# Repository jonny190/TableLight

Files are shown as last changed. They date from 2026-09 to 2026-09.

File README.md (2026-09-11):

# TableLight

A 3D-printable, battery-powered, USB-C rechargeable table lamp in the classic "Poldina" shape - honeycomb
disc base, thin stem, down-firing cone shade with a white top - running [WLED](https://kno.wled.ge/) on an
ESP32, with a capacitive touch pad hidden under the white top plate.

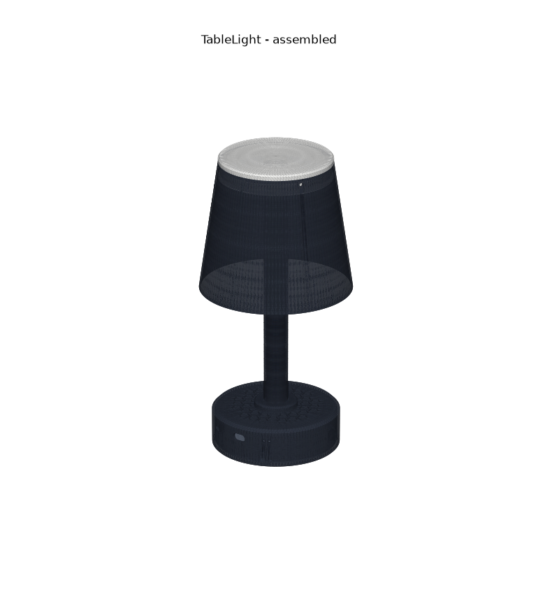
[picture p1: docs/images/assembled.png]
assembled


| | |
|---|---|
| Size | Ø118 x 36 mm base, Ø22 stem, shade Ø140 -> Ø104 x 120 mm, 279 mm tall overall |
| Light | 24-LED SK6812 RGBW (or WS2812B) ring under the head, shining down through a diffuser; optional second 16-LED ring |
| Power | 1 **or** 2 x 18650 Li-ion in parallel (1S) in the base, USB-C charging (1 A) in the base, runs while charging |
| Control | WLED app / web UI / Home Assistant + touch on the white top (ESP32 native touch) |
| Electronics | one custom Ø110 mm PCB in the base (KiCad board + PCBWay Gerber/BOM/CPL package included); flashes WLED over the same USB-C port |
| Runtime | ~5 h at full reading brightness, ~12 h at mood brightness with two 3500 mAh cells (half with one cell) |

## What is in this repository

```
cad/tablelight.py          parametric CAD (Python: trimesh + manifold) - ALL dimensions live here
cad/stl/                   ready-to-print STL files (6 parts)
hardware/pcb/              custom controller PCB: SKiDL circuit, KiCad 7 board (kicad/), PCBWay fab package
                           (fab/: Gerbers, drill, BOM, pick-and-place), board generator, design notes
firmware/wled/             WLED build override + settings for this lamp
docs/BOM.md                complete bill of materials (printed parts, electronics, hardware, consumables)
docs/PRINTING.md           print settings and orientation per part
docs/ASSEMBLY.md           step-by-step build
docs/WLED_SETUP.md         WLED configuration (pins, 2D matrix, touch button, battery, current limit)
docs/images/               renders, section drawing, PCB placement, block diagram
```

## The parts

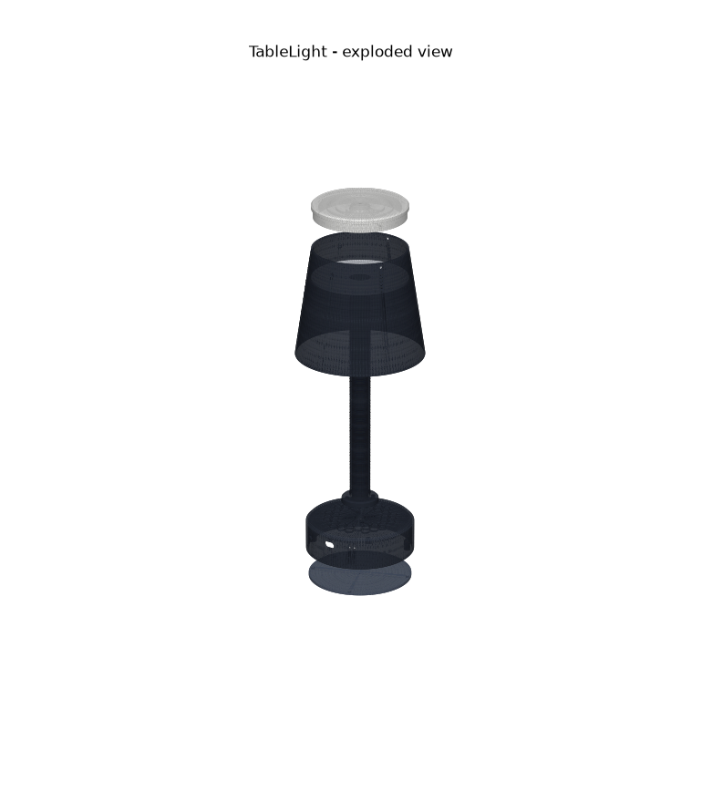
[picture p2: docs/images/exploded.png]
exploded


| STL | Qty | What it does |
|---|---|---|
| `base_shell.stl` | 1 | Honeycomb-topped base disc: the PCB hangs under its deck (components facing down), USB-C, power switch and charge LEDs in the side wall, 1-2 x 18650 inside |
| `base_bottom_plate.stl` | 1 | Screw-on floor with rubber feet; remove it to reach the batteries, buttons and connectors |
| `stem.stl` | 1 | Ø22 hollow stem with a Ø40 foot flange; screwed to the deck from below, carries the wires to the head |
| `head_plate.stl` | 1 | White top: stem socket, two LED-ring channels on the underside, skirt that the shade screws to, touch-pad recess |
| `cone_shade.stl` | 1 | Opaque cone Ø140 -> Ø104, open at the bottom; 3 nubs hold the diffuser, 3 radial screws hold it to the head |
| `head_diffuser.stl` | 1 | Ø104 translucent disc 14 mm under the LED ring so you never see bare LEDs from below |

Section through the assembled lamp (all clearances are modelled, nothing is glued):

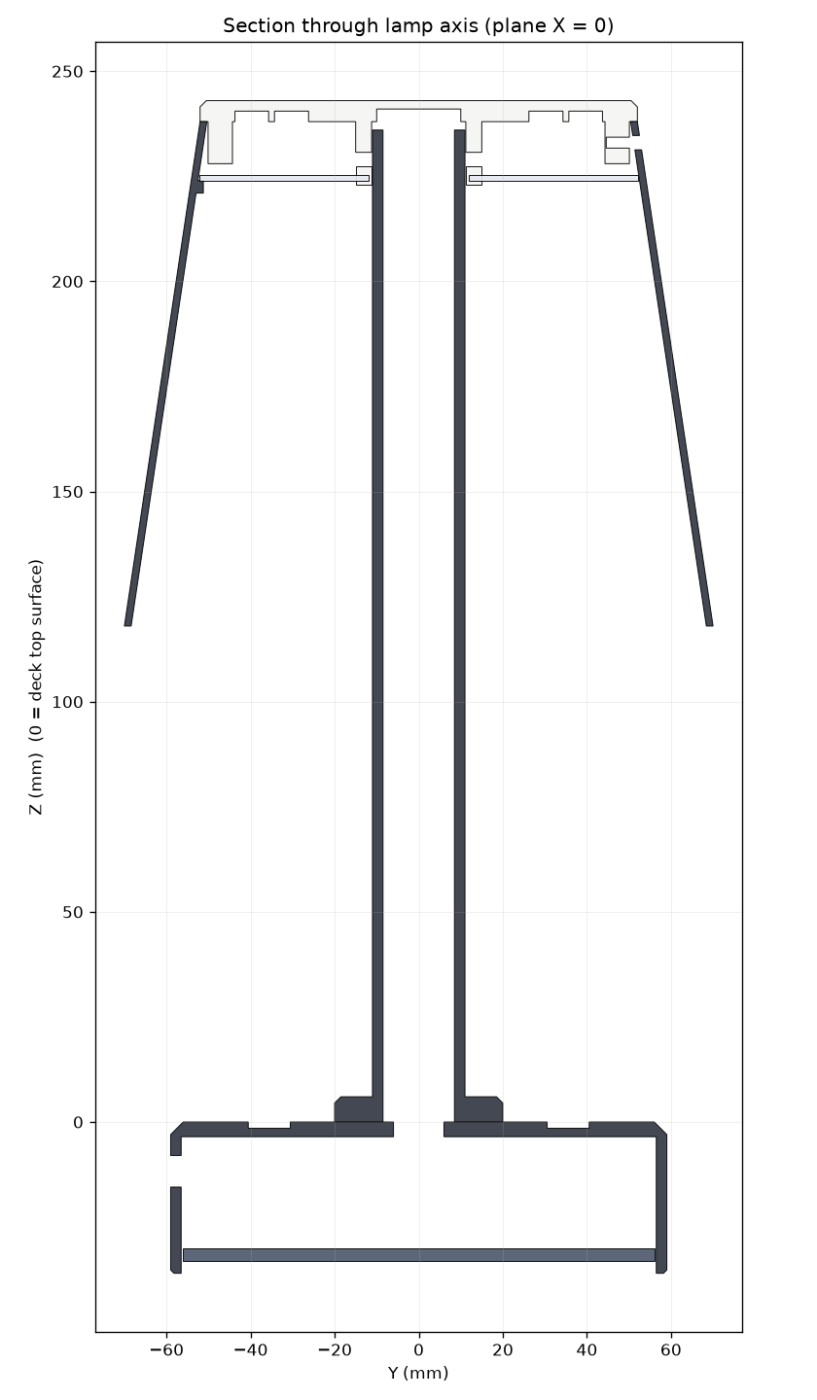
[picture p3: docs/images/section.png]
section


## Electronics in one picture

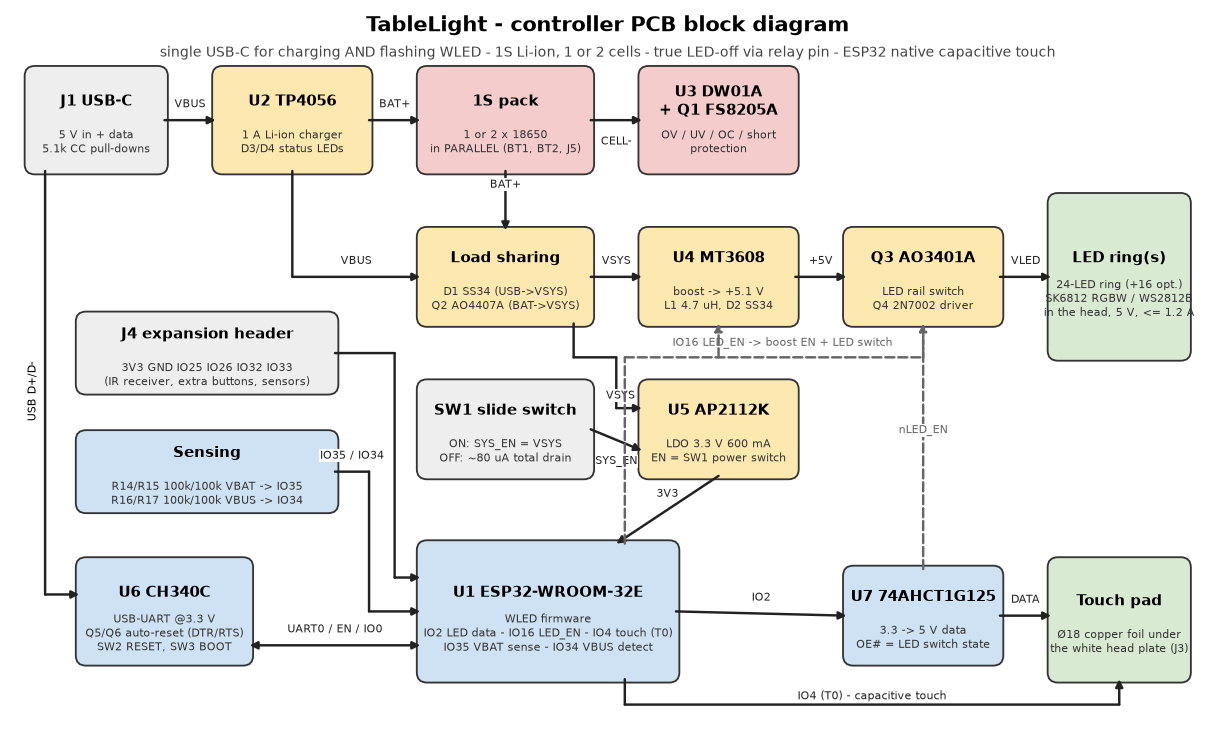
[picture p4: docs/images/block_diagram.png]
block diagram


Power path: USB-C -> TP4056 charger -> 1S pack (DW01A/FS8205A protected) -> load-share (Schottky + P-FET)
-> `VSYS` -> MT3608 boost 5.1 V -> P-FET LED switch -> LED ring in the head (via the stem); `VSYS` -> 3.3 V LDO -> ESP32-WROOM-32E.
The USB-C data lines go to a CH340C with auto-reset, so WLED is flashed through the charging port.
A slide switch in the base wall is the hard off (about 80 uA drain). WLED's "relay pin" cuts the LED rail so
standby is only the ESP32.

See `hardware/pcb/README.md` for the design rationale and `hardware/pcb/SCHEMATIC.md` for every net.

## Build order (short version)

1. Print the six parts (`docs/PRINTING.md`). Fit 12 x M3 heat-set inserts.
2. Order the PCB: upload `hardware/pcb/fab/tablelight-gerbers.zip` to PCBWay (`hardware/pcb/fab/README.md` has the form values). Flash WLED (`docs/WLED_SETUP.md`).
3. Tape the LED ring into the head plate, stick the touch foil in its recess, run the wires down the stem (`docs/ASSEMBLY.md`).
4. Screw the stem to the deck, plug the PCB in, screw the PCB to the deck bosses, fit 1 or 2 cells, screw the floor on.
5. Push the diffuser up into the cone, screw the cone to the head, push the head onto the stem and fix it with two screws. Done.

## Regenerating the CAD / PCB files

```
pip install -r requirements.txt
python3 cad/tablelight.py                    # STLs -> cad/stl, renders -> docs/images
python3 hardware/pcb/tablelight_netlist.py   # tablelight.net, bom_pcb.csv, SCHEMATIC.md
python3 hardware/pcb/board_outline.py        # outline.dxf, placement.svg, PLACEMENT.md
python3 hardware/pcb/build_board.py          # KiCad board -> autoroute -> DRC -> fab/ (needs KiCad 7 + freerouting.jar)
python3 docs/block_diagram.py                # block_diagram.svg/.png
```

Change a value in the `P = dict(...)` block at the top of `cad/tablelight.py` (shade size and taper, stem length,
base diameter, honeycomb size, ring diameters...) and everything that depends on it - head socket, cone screw
positions, wall openings, PCB placement drawing - follows. The stem is 236 mm tall as printed; set `stem_len`
lower if your printer's Z is under 240 mm.

## Safety notes

* Cells in parallel must be the same model and within ~0.1 V of each other when inserted. Never mix a fresh
  and a flat cell.
* The board has over/under-voltage, over-current and short protection (DW01A + FS8205A), but a lamp is a closed
  plastic box: keep the WLED current limit at or below 1200 mA and do not leave it charging on a cushion.
* Use a 5 V USB-C supply rated 2 A or more when charging and running at the same time.

## License

MIT for the code and design files. WLED is licensed separately by its authors.

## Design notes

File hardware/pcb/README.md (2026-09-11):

# TableLight controller PCB

Round Ø110 mm, 2 layer, 1.6 mm FR4. Lives in the base, components facing down, screwed to four bosses
under the base deck. One board does everything: charging, protection, boost, ESP32 + WLED, USB flashing,
LED power switching, touch input, battery sensing.

**Ready to order:** `fab/tablelight-gerbers.zip` (+ `fab/tablelight-bom.csv`, `fab/tablelight-cpl.csv` for
assembly). Ordering parameters and a pre-order checklist are in `fab/README.md`. The KiCad 7 board is
`kicad/tablelight.kicad_pcb`: hand-placed, autorouted (freerouting, 2 layers, 58 vias), GND pours both
sides, KiCad DRC clean (0 unconnected, 0 clearance/edge/hole/courtyard errors; remaining report entries
are silkscreen cosmetics).

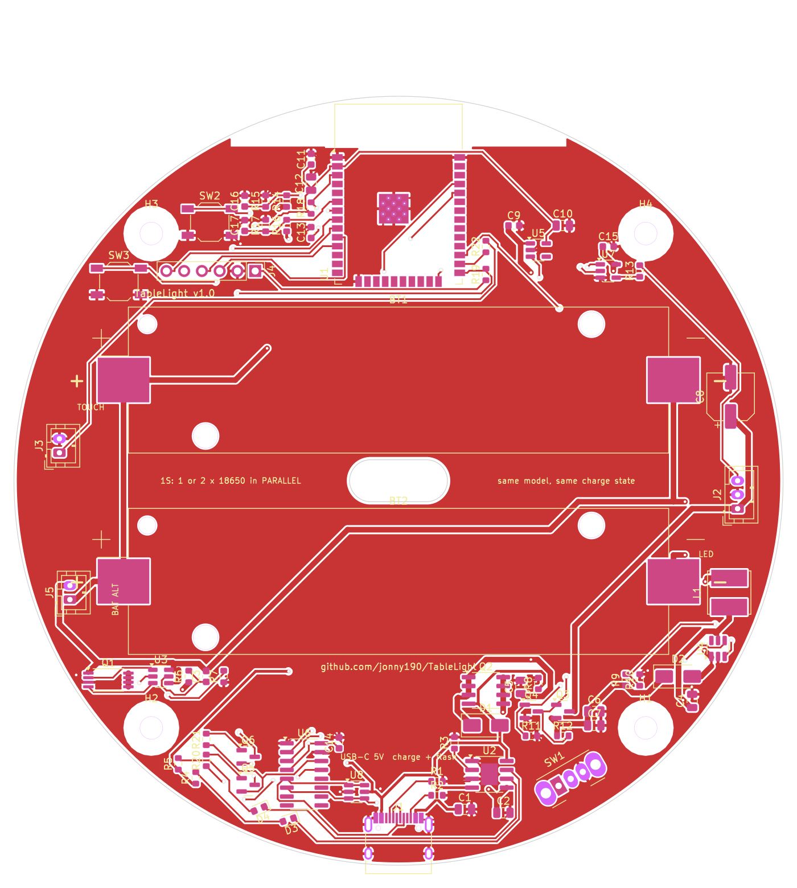
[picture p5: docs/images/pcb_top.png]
top


block diagram

| File | What |
|---|---|
| `build_board.py` | **the board** (KiCad 7 pcbnew API): places every footprint from the table inside it, autoroutes with freerouting, pours GND, runs DRC, exports `fab/` |
| `kicad/tablelight.kicad_pcb` | the finished board; `kicad/drc_report.txt` is the DRC of exactly this file |
| `fab/` | PCBWay package: Gerbers + drill zip, assembly BOM, pick-and-place, ordering notes |
| `tablelight_netlist.py` | **the circuit** (SKiDL). Run it to regenerate the three files below |
| `tablelight.net` | KiCad netlist with footprints assigned. pcbnew: *File > Import Netlist* |
| `SCHEMATIC.md` | every net with every pin, plus per-component pin tables |
| `bom_pcb.csv` | PCB bill of materials (refs, values, example MPNs, footprints) |
| `board_outline.py` | reads the enclosure parameters and writes the three files below |
| `outline.dxf` | Edge.Cuts (Ø110 circle + centre wire slot) and reference layers. pcbnew: *File > Import > Graphics* |
| `placement.svg` / `PLACEMENT.md` | where the connectors, holders, module and keep-outs must go |

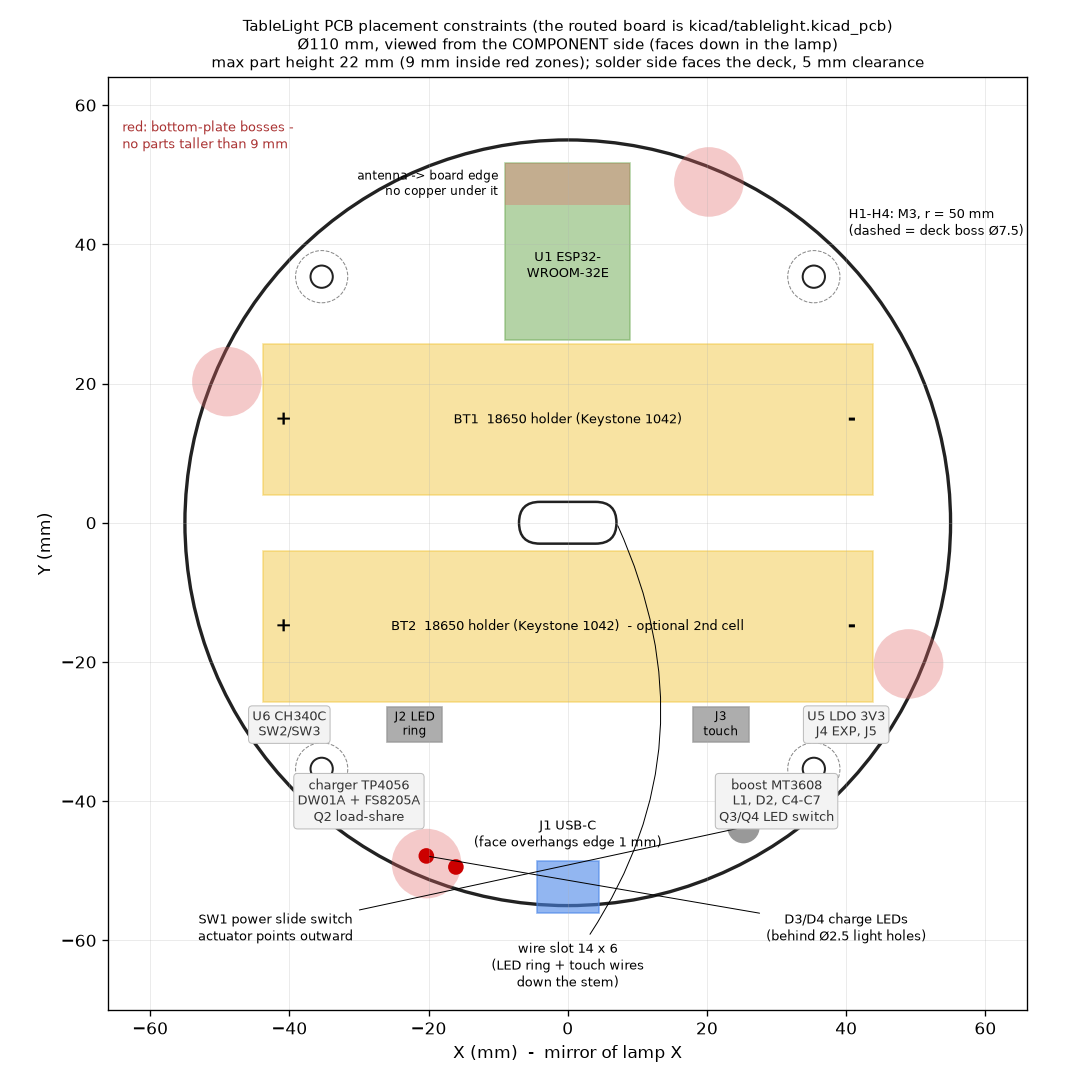
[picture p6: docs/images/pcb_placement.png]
placement


## Regenerating the board

```
sudo apt install kicad            # KiCad 7 (pcbnew Python module + kicad-cli)
curl -L -o hardware/pcb/tools/freerouting.jar \
     https://github.com/freerouting/freerouting/releases/download/v1.9.0/freerouting-1.9.0.jar
python3 hardware/pcb/build_board.py               # place -> route -> zones -> DRC -> fab/
```

`build_board.py` reads the circuit from `tablelight_netlist.py` and the mechanical constraints from
`cad/tablelight.py`; component positions are the `PLACEMENT` table at the top of the script (KiCad
coordinates, Y down, component side view). Change a position there and rerun: the router, pours, DRC and
Gerbers are regenerated. Design rules baked in: 0.25 mm signal / 0.8 mm power tracks, 0.2 mm clearance,
0.7/0.35 mm vias, 0.4 mm copper-to-edge, GND pour both layers with thermal reliefs.

Keep-outs that the script enforces: no copper under the module antenna (both layers), no copper on the
component side within 4 mm of the four mounting holes (screw heads), courtyards clear of the two
Keystone 1042 holders (87.6 x 21.7 mm each).

If you would rather lay it out by hand: import `tablelight.net` into an empty pcbnew, import `outline.dxf`
onto Edge.Cuts, and follow `PLACEMENT.md`. Power nets (`BAT+`, `CELL-`, `GND`, `VSYS`, `+5V`, `VLED`) carry
up to 2.5 A: 0.8 mm+ traces or pours. Height limits from the enclosure: 22 mm anywhere on the component
side, 9 mm inside the four boss zones, 3 mm of lead length on the solder side.

## Design notes and calculations

**Cells.** 1S, one or two 18650 in parallel. Parallel cells need no balancing; they must be the same model
and within ~0.1 V when inserted. `J5` is a JST-PH alternative for a wire-lead holder or a pouch cell.

**Protection.** DW01A + FS8205A, the same topology as the ubiquitous TP4056 module: the two FETs sit in the
cell-negative path, `CELL-` is the raw cell terminal and `GND` is the protected side. Over-discharge 2.4 V,
over-charge 4.3 V, over-current ~3 A (with the 8205A's 2 x 25 mOhm). Dissipation at 2.5 A: 0.3 W.

**Charger.** TP4056, `R3` = 1.2k -> 1.0 A. 2 x 3500 mAh charge in about 8 h, one cell in 4 h. Use `R3` = 2k
(0.58 A) if it will mostly be charged from a laptop port. Dissipation worst case (5 V - 3.0 V) x 1 A = 2 W at
the start of charge: give U2's pad a big pour, the IC throttles thermally anyway. `TEMP` is grounded (no NTC).
CC1/CC2 pull-downs (5.1k) so USB-C to USB-C cables and PD chargers supply 5 V.

**Load sharing.** `D1` (SS34) feeds `VSYS` from `VBUS` while plugged in; `Q2` (AO4407A, 12 mOhm) connects the
pack to `VSYS` only when `VBUS` is absent (gate tied to `VBUS`, `R8` pull-down). The charger therefore only
ever sees the cell, so termination works, and the lamp runs at full power while charging. Q2 drop at 2.5 A:
30 mV.

**Boost.** MT3608 at 1.2 MHz, `R9`/`R10` = 75k/10k -> 5.1 V. 4.7 uH / 4 A inductor, 2 x 22 uF in, 2 x 22 uF
out plus 100 uF on `VLED`. Practical continuous output from a 3.3 V cell is about 1.5 A at 5 V, hence the
WLED current limit of 1.2 A (24 + 16 LEDs at full white would ask for 2.4 A). `EN` is driven by `LED_EN`
(GPIO16), so the converter idles when the light is off.

**LED rail switch.** `Q3` (AO3401A) between `+5V` and `VLED`, driven by `Q4` (2N7002) from `LED_EN`. WLED's
"relay pin" feature raises GPIO16 whenever the strip is on. `R11` keeps the LEDs off during boot. With the
rail off the ring draws nothing, so standby is only the ESP32 (~80 mA with WiFi, ~10 mA with WiFi sleep).

**Level shifter.** SN74AHCT1G125 powered from `+5V`, input from GPIO2, 330 R into the data line. Its `OE#`
is tied to the Q3 gate node, so the data output is high-impedance while the rail is off - no back-powering
the ring through its data pin.

**3.3 V.** AP2112K-3.3 from `VSYS` (works from 3.0 to 5 V input, 250 mV dropout at 600 mA). Its `EN` pin is
the power switch `SW1`: OFF disables the LDO, the ESP32 dies, `LED_EN` falls, boost and LED rail switch off.
Off-state drain is about 80 uA (LDO + DW01 + the two 100k/100k dividers + the boost FB divider): years.

**USB-UART.** CH340C at 3.3 V (`V3` tied to `VCC`), no crystal. Standard NodeMCU auto-reset with two NPNs
(DTR/RTS -> EN/IO0) so esptool and the WLED web installer work hands-free. `SW2` RESET and `SW3` BOOT for
manual recovery. USBLC6-2SC6 on D+/D- is optional ESD protection.

**ESP32 pins.** GPIO2 LED data, GPIO16 LED rail enable (relay pin), GPIO4 (T0) touch, GPIO35 battery voltage
(100k/100k, x2.0), GPIO34 VBUS detect (100k/100k), GPIO25/26/32/33 on the expansion header `J4`. Strapping
pins 12 and 15 are left unconnected; GPIO0 has a 10k pull-up.

**Touch.** ESP32 native capacitive sensing through 2 mm of PLA with a Ø18 foil disc under the head plate.
`R22` (1k) is ESD/series protection; use 0 R if the sensitivity is marginal. The touch wire runs 250 mm down
the stem next to the LED wires: keep it away from the data wire if possible (twist it with the GND wire).

## Bring-up (bench, before installing)

1. No cells. Plug USB-C: D3 or D4 flashes, `VSYS` ~4.6 V, `3V3` = 3.3 V with `SW1` on, the CH340 enumerates.
2. Flash WLED. It should boot and start its AP.
3. Insert one cell. Unplug USB: the lamp keeps running from the cell (Q2). `BAT+` divider reads on GPIO35.
4. Connect the ring to `J2`, turn the light on in WLED: `VLED` = 5.1 V only while on.
5. Plug USB with the cell in: D3 (red) while charging, D4 (green) when done. Q2 should be cold.

## Ordering

See `fab/README.md` for the PCBWay form values. Any 2-layer service works (JLCPCB, Aisler, OSH Park take
the same zip). All SMD parts are on one side; the THT parts (JST headers, pin header, slide switch) and the
SMD-mount 18650 holders are a 20 minute hand solder if you do not order assembly.

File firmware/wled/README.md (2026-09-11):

# WLED firmware notes

* `platformio_override.ini` - drop into a WLED checkout to build the `tablelight` environment with this
  board's pin defaults and the Battery usermod. Verified against the WLED 0.15 build-flag names
  (`DATA_PINS`, `RLYPIN`, `BTNPIN`, `BTNTYPE`, `USERMOD_BATTERY_*`); if a future WLED renames one, the compiler
  will tell you and the equivalent setting can always be made in the web UI (`docs/WLED_SETUP.md`).
* No custom code is required. Everything the lamp does (touch toggle, LED rail switching, 2D effects,
  battery readout) is stock WLED functionality configured for these pins. The LED count default is 24 (one ring); set 40 in the UI if you fit the second ring.

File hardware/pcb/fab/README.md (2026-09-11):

# TableLight PCB - PCBWay fabrication package

Everything in this folder is generated by `../build_board.py` from the KiCad board
`../kicad/tablelight.kicad_pcb`. Upload `tablelight-gerbers.zip` to PCBWay; if you also want them to
assemble the SMD side, add `tablelight-bom.csv` and `tablelight-cpl.csv`.

| File | Use |
|---|---|
| `tablelight-gerbers.zip` | Gerber RS-274X (copper, mask, paste, silk, outline) + Excellon drill + drill map PDF |
| `tablelight-bom.csv` | PCBWay assembly BOM (Designator, Qty, MPN, Description, Package, SMD/THT) |
| `tablelight-cpl.csv` | pick-and-place (Designator, Mid X, Mid Y, Layer, Rotation), top side, mm |
| `../kicad/tablelight.kicad_pcb` | the board itself (KiCad 7) for any edits |
| `../kicad/drc_report.txt` | DRC report of the exact board that was exported |

## PCBWay order form - "PCB Instant Quote"

| Field | Value |
|---|---|
| Board type | Single pieces |
| Size | 110 x 110 mm (round board, Ø110, drawn in the Edge.Cuts layer; there is a 14 x 6 mm internal slot) |
| Quantity | 5 (minimum) |
| Layers | 2 |
| Material | FR-4, TG 150 |
| Thickness | 1.6 mm |
| Min track / spacing | 6/6 mil (the board uses 0.25 mm / 0.2 mm - 8 mil - so 6/6 is plenty) |
| Min hole size | 0.3 mm (smallest drill on the board is 0.3 mm; the module's thermal vias are 0.35 mm) |
| Solder mask | black (the base is black) or any colour |
| Silkscreen | white |
| Surface finish | HASL lead-free (ENIG if you order assembly) |
| Via process | tenting vias |
| Finished copper | 1 oz |
| Remove product number | yes (or let PCBWay put it under a battery holder) |

## Assembly (optional, "PCB Assembly" quote)

* Assembly side: **top only** (single-sided SMD). The board has no components on the bottom.
* Supply parts: **turnkey** with the BOM. Fill in the *Manufacturer* column or let PCBWay source
  equivalents; the *Mfg Part #* column gives a known-good part for each line.
* THT parts (BT1, BT2, J2-J5, SW1) can be left off the assembly order and hand soldered in 20 minutes.
  The USB-C receptacle (J1) is SMD with through-hole shield legs: PCBWay handles it as SMD.
* The 18650 holders (Keystone 1042) are SMD-mount and heavy; if you include them in the assembly,
  ask for them to be soldered last.
* Pad 1 of each holder is wired as the **positive** terminal (silk "+" marks at the −X end of the board).
  Confirm that orientation against the holder body before installing cells.

## What was checked before export

* KiCad DRC on the exported board (report in `../kicad/drc_report.txt`): **0 unconnected pads, 0
  clearance / edge / hole / courtyard / keep-out errors**. The report still lists ~45 silkscreen items
  (reference text touching a neighbour's pad or another label - the Gerbers are exported with silk
  subtracted from the solder-mask openings, and PCBWay clips silk on pads anyway) and 72 "footprint
  not in library table" notices, which only mean the board was generated without a project library table.
* Net list against `../tablelight_netlist.py` (same object graph feeds both the netlist and the board).
* Antenna keep-out: no copper on either layer under the ESP32 module antenna, module edge at the board edge.
* Screw-head keep-outs: no copper on the component side within 4 mm of the four M3 mounting holes.
* Mechanical positions of J1 (USB-C), SW1 and D3/D4 match the openings in `cad/tablelight.py`.

## What you should still look at before paying

This board was placed by hand (the table in `../build_board.py`) and routed by an autorouter
(freerouting), then checked by DRC. That makes it manufacturable, not necessarily pretty. Ten minutes
in KiCad are well spent on:

1. Open `../kicad/tablelight.kicad_pcb`, press `B` to refill zones, run DRC once more.
2. Look at the charger area (U2, D1, Q2): make sure the GND pour connects to the TP4056 exposed pad
   with several vias (thermal relief spokes are set to 0.4 mm).
3. The boost inductor loop (L1 - U4 pin 1 - D2): keep the autorouted tracks short; if freerouting
   detoured, drag them.
4. Confirm the USB-C receptacle's silkscreen edge line sits just outside the board edge (face 1 mm past
   the edge is intentional so the plug reaches through the 2.5 mm wall).

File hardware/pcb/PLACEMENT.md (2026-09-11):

# TableLight PCB - placement constraints (KiCad coordinates)

Origin = board centre. KiCad Y axis points DOWN, so KiCad (x, y) = (x_view, -y_view). Viewed from the component side.

Generated from `cad/tablelight.py` parameters by `board_outline.py`.

| Item | KiCad (x, y) mm | Size / notes |
|---|---|---|
| Board outline | (0, 0) | circle Ø110 mm (`outline.dxf`, layer Edge.Cuts) |
| Wire slot | (0, 0) | 14 x 6 mm rounded slot in the board centre (under the Ø12 deck hole / stem bore); keep 1 mm copper clearance |
| H1 mounting hole | (+35.36, -35.36) | Ø3.2 mm; deck boss Ø7.5 mm lands on the SOLDER side around it |
| H2 mounting hole | (-35.36, -35.36) | Ø3.2 mm; deck boss Ø7.5 mm lands on the SOLDER side around it |
| H3 mounting hole | (-35.36, +35.36) | Ø3.2 mm; deck boss Ø7.5 mm lands on the SOLDER side around it |
| H4 mounting hole | (+35.36, +35.36) | Ø3.2 mm; deck boss Ø7.5 mm lands on the SOLDER side around it |
| J1 USB-C body | (+0.00, +52.33) | receptacle mating face at y_view = -56.0 (1 mm past the edge), pointing -Y |
| SW1 slide switch | (+25.25, +43.73) | actuator radially outward at 300 deg (view); base slot 9.0x4.0 mm |
| D3 CHRG LED | (-16.07, +49.45) | at board edge, light hole Ø2.5 in the base wall |
| D4 STDBY LED | (-20.32, +47.87) | at board edge, light hole Ø2.5 in the base wall |
| U1 ESP32 module | (+0.00, -38.95) | 18.0x25.5 mm, antenna toward +Y_view (board edge); antenna zone 6.0 mm: no copper |
| Stem flange screw heads (solder side) | r = 14.5 mm at 45/135/225/315 deg | M3 heads sit in the 5 mm gap above the board: keep the solder side flat there (no tall THT leads) |
| BT1 18650 holder | (+0.00, -14.85) | 87.6x21.7 mm, long axis along X, '+' (pad 1) toward -X_view |
| BT2 18650 holder | (+0.00, +14.85) | 87.6x21.7 mm, long axis along X, '+' (pad 1) toward -X_view |
| J2 LED ring | (-22.00, +29.00) | JST-PH; wires run along the holder edge to the centre slot |
| J3 touch | (+22.00, +29.00) | JST-PH; wires run along the holder edge to the centre slot |
| Boss keep-out 1 | (-48.97, -20.28) | Ø10 mm zone: parts taller than 9 mm not allowed here |
| Boss keep-out 2 | (+20.28, -48.97) | Ø10 mm zone: parts taller than 9 mm not allowed here |
| Boss keep-out 3 | (+48.97, +20.28) | Ø10 mm zone: parts taller than 9 mm not allowed here |
| Boss keep-out 4 | (-20.28, +48.97) | Ø10 mm zone: parts taller than 9 mm not allowed here |

* Max component height anywhere on the component side: **22 mm** (bottom plate is 22.9 mm below the component face).
* Solder side: 5 mm clearance to the deck. Keep THT pins trimmed below 3 mm.
* Antenna zone: keep the +Y edge of the module flush with, or overhanging, the board edge and copper-free on all layers.
* Thermals: pour a large copper area (both sides, stitched) under the TP4056 EP and around D1/Q2; the enclosure is closed PLA.
* Battery holders carry up to ~2.5 A: use >= 1.5 mm traces or pours for BAT+, CELL-, GND, VSYS, +5V, VLED.

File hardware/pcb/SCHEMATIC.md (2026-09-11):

# TableLight controller PCB - schematic (net list form)

Generated by `tablelight_netlist.py`. The block diagram is in `../../docs/images/block_diagram.svg`; the design rationale is in `README.md` next to this file. Import `tablelight.net` into KiCad pcbnew (File > Import Netlist) to get all footprints with ratsnest, then lay the board out on `outline.dxf`.

## Nets

| Net | Pins | Connected pins |
|---|---|---|
| `GND` | 51 | C1.2, C2.2, C4.2, C5.2, C6.2, C7.2, C8.2 (-), C9.2, C10.2, C11.2, C12.2, C13.2, C14.2, C15.2, C16.2, C17.2, J1.A1 (GND), J1.A12 (GND), J1.B1 (GND), J1.B12 (GND), J1.S1 (SHIELD), J2.2, J3.2, J4.2, Q1.3 (S2), Q4.2 (S), R1.2, R2.2, R3.2, R7.1, R8.2, R10.2, R11.2, R15.2, R17.2, SW1.3, SW2.2, SW3.2, U1.1 (GND), U1.15 (GND), U1.38 (GND), U1.39 (GND), U2.1 (TEMP), U2.3 (GND), U2.9 (EP), U4.2 (GND), U5.2 (GND), U6.1 (GND), U6.15 (R232), U7.3 (GND), U8.2 (GND) |
| `VBUS` | 14 | C1.1, D1.2 (A), J1.A4 (VBUS), J1.A9 (VBUS), J1.B4 (VBUS), J1.B9 (VBUS), Q2.4 (G), R4.1, R5.1, R8.1, R16.1, U2.4 (VCC), U2.8 (CE), U8.5 (VBUS) |
| `3V3` | 11 | C10.1, C11.1, C12.1, C14.1, J4.1, R18.1, R19.1, U1.2 (3V3), U5.5 (VOUT), U6.16 (VCC), U6.4 (V3) |
| `BAT+` | 11 | BT1.1 (+), BT2.1 (+), C2.1, J5.1, Q2.5 (D), Q2.6 (D), Q2.7 (D), Q2.8 (D), R6.1, R14.1, U2.5 (BAT) |
| `VSYS` | 11 | C4.1, C5.1, C9.1, D1.1 (K), L1.1, Q2.1 (S), Q2.2 (S), Q2.3 (S), SW1.1, U4.5 (IN), U5.1 (VIN) |
| `+5V` | 8 | C6.1, C7.1, C15.1, D2.1 (K), Q3.2 (S), R9.1, R12.1, U7.5 (VCC) |
| `CELL-` | 7 | BT1.2 (-), BT2.2 (-), C3.2, J5.2, Q1.1 (S1), U3.4 (TD), U3.6 (GND) |
| `EN` | 5 | C13.1, Q5.3 (C), R18.2, SW2.1, U1.3 (EN) |
| `USB_D+` | 5 | J1.A6 (D+), J1.B6 (D+), U6.5 (UD+), U8.1 (IO1), U8.6 (IO1) |
| `USB_D-` | 5 | J1.A7 (D-), J1.B7 (D-), U6.6 (UD-), U8.3 (IO2), U8.4 (IO2) |
| `IO0` | 4 | Q6.3 (C), R19.2, SW3.1, U1.25 (IO0) |
| `LED_EN` | 4 | Q4.1 (G), R11.1, U1.27 (IO16), U4.4 (EN) |
| `PROT_FET_D` | 4 | Q1.5 (D2), Q1.6 (D2), Q1.7 (D1), Q1.8 (D1) |
| `VBAT_SENSE` | 4 | C16.1, R14.2, R15.1, U1.7 (IO35) |
| `VBUS_DET` | 4 | C17.1, R16.2, R17.1, U1.6 (IO34) |
| `nLED_EN` | 4 | Q3.1 (G), Q4.3 (D), R12.2, U7.1 (OE#) |
| `BOOST_FB` | 3 | R9.2, R10.1, U4.3 (FB) |
| `BOOST_SW` | 3 | D2.2 (A), L1.2, U4.1 (SW) |
| `DTR` | 3 | Q6.2 (E), R20.1, U6.13 (DTR#) |
| `DW01_VCC` | 3 | C3.1, R6.2, U3.5 (VCC) |
| `RTS` | 3 | Q5.2 (E), R21.1, U6.14 (RTS#) |
| `VLED` | 3 | C8.1 (+), J2.1, Q3.3 (D) |
| `CC1` | 2 | J1.A5 (CC1), R1.1 |
| `CC2` | 2 | J1.B5 (CC2), R2.1 |
| `CHRG` | 2 | D3.1 (K), U2.7 (CHRG) |
| `DTR_B` | 2 | Q5.1 (B), R20.2 |
| `DW01_CS` | 2 | R7.2, U3.2 (CS) |
| `DW01_OC` | 2 | Q1.4 (G2), U3.3 (OC) |
| `DW01_OD` | 2 | Q1.2 (G1), U3.1 (OD) |
| `IO25` | 2 | J4.3, U1.10 (IO25) |
| `IO26` | 2 | J4.4, U1.11 (IO26) |
| `IO32` | 2 | J4.5, U1.8 (IO32) |
| `IO33` | 2 | J4.6, U1.9 (IO33) |
| `LED_DATA` | 2 | U1.24 (IO2), U7.2 (A) |
| `LED_DATA_5V` | 2 | R13.1, U7.4 (Y) |
| `LED_DOUT` | 2 | J2.3, R13.2 |
| `N$1` | 2 | R3.1, U2.2 (PROG) |
| `N$2` | 2 | D3.2 (A), R4.2 |
| `N$3` | 2 | D4.2 (A), R5.2 |
| `RTS_B` | 2 | Q6.1 (B), R21.2 |
| `STDBY` | 2 | D4.1 (K), U2.6 (STDBY) |
| `SYS_EN` | 2 | SW1.2 (COM), U5.3 (EN) |
| `TOUCH` | 2 | R22.1, U1.26 (IO4) |
| `TOUCH_PAD` | 2 | J3.1, R22.2 |
| `U0RXD` | 2 | U1.34 (RXD0), U6.2 (TXD) |
| `U0TXD` | 2 | U1.35 (TXD0), U6.3 (RXD) |

## Components

| Refs | Qty | Value | Description | MPN / example | Footprint | Notes |
|---|---|---|---|---|---|---|
| BT1 | 1 | 18650 | 18650 PCB-mount holder | Keystone 1042 (or BH-18650-PC equiv.) | BatteryHolder_Keystone_1042_1x18650 |  |
| BT2 | 1 | 18650 (optional 2nd cell) | 18650 PCB-mount holder | Keystone 1042 (or BH-18650-PC equiv.) | BatteryHolder_Keystone_1042_1x18650 |  |
| C1, C2, C10, C12 | 4 | 10uF 10V | Capacitor 0805 X5R |  | C_0805_2012Metric |  |
| C3, C11, C14, C15, C16, C17 | 6 | 100nF | Capacitor 0603 X7R |  | C_0603_1608Metric |  |
| C4, C5, C6, C7 | 4 | 22uF 10V | Capacitor 0805 X5R |  | C_0805_2012Metric |  |
| C8 | 1 | 100uF 6.3V | Electrolytic / polymer cap SMD 6.3x5.4 |  | CP_Elec_6.3x5.4 | LED rail bulk |
| C9, C13 | 2 | 1uF | Capacitor 0603 X7R |  | C_0603_1608Metric | EN reset delay |
| D1, D2 | 2 | SS34 | Schottky diode SMA |  | D_SMA | USB -> VSYS |
| D3 | 1 | RED | LED 0603 |  | LED_0603_1608Metric | CHRG: on while charging |
| D4 | 1 | GREEN | LED 0603 |  | LED_0603_1608Metric | STDBY: on when charge complete |
| H1, H2, H3, H4 | 4 | M3 | M3 mounting hole (r=45 mm, 45/135/225/315 deg) | - | MountingHole_3.2mm_M3 |  |
| J1 | 1 | USB-C 16P | USB-C receptacle 16 pin, top mount | HRO TYPE-C-31-M-12 | USB_C_Receptacle_HRO_TYPE-C-31-M-12 |  |
| J2 | 1 | LED RING | JST PH 2.0 mm 3 pin | B3B-PH-K-S | JST_PH_B3B-PH-K_1x03_P2.00mm_Vertical | 1 = VLED (+5V), 2 = GND, 3 = DATA -> LED ring(s) in the head, via the stem |
| J3 | 1 | TOUCH | JST PH 2.0 mm 2 pin | B2B-PH-K-S | JST_PH_B2B-PH-K_1x02_P2.00mm_Vertical | 1 = pad, 2 = GND (optional shield) |
| J4 | 1 | EXP | Pin header 1x6 2.54 mm (expansion) | generic | PinHeader_1x06_P2.54mm_Vertical | 3V3 GND IO25 IO26 IO32 IO33 (IR receiver, extra buttons, sensors) |
| J5 | 1 | BAT ALT | JST PH 2.0 mm 2 pin | B2B-PH-K-S | JST_PH_B2B-PH-K_1x02_P2.00mm_Vertical | alternative: wire-lead holder / pouch cell, parallel to BT1/BT2 |
| L1 | 1 | 4.7uH 4A | Power inductor 6x6 mm shielded |  | L_Bourns_SRN6045TA | e.g. Bourns SRN6045TA-4R7Y or any 6x6 shielded, Isat >= 4 A |
| Q1 | 1 | FS8205A | Dual N-MOSFET common drain, 20 V, 6 A (battery protection) | FS8205A | TSSOP-8_4.4x3mm_P0.65mm |  |
| Q2 | 1 | AO4407A | P-MOSFET -30 V 12 A 12 mOhm (load sharing) | AO4407A | SOIC-8_3.9x4.9mm_P1.27mm | load-share P-FET; off while USB present |
| Q3 | 1 | AO3401A | P-MOSFET -30 V 4 A (LED rail switch) | AO3401A | SOT-23 | LED rail switch |
| Q4 | 1 | 2N7002 | N-MOSFET 60 V 300 mA | 2N7002 | SOT-23 | inverts LED_EN for Q3 |
| Q5, Q6 | 2 | MMBT3904 | NPN transistor (auto-reset) | MMBT3904 | SOT-23 | auto-reset: EN; auto-reset: IO0 |
| R1, R2 | 2 | 5.1k | Resistor 0603 1% |  | R_0603_1608Metric | CC1 Rd -> sink advertises 5 V device; CC2 Rd |
| R3 | 1 | 1.2k | Resistor 0603 1% |  | R_0603_1608Metric | PROG: 1.2k = 1.0 A charge; use 2k for 0.58 A (weak USB ports) |
| R4, R5, R7, R22 | 4 | 1k | Resistor 0603 1% |  | R_0603_1608Metric | DW01 CS sense; touch series / ESD; 0R also fine |
| R6 | 1 | 100R | Resistor 0603 1% |  | R_0603_1608Metric | DW01 VCC filter |
| R8, R11, R14, R15, R16, R17 | 6 | 100k | Resistor 0603 1% |  | R_0603_1608Metric | LED_EN pull-down: LEDs off during boot; VBAT divider top (x2.0 in WLED battery usermod); VBUS bleed / Q2 gate pull-down; VBUS present detect |
| R9 | 1 | 75k | Resistor 0603 1% |  | R_0603_1608Metric | FB divider: Vout = 0.6*(1+75/10) = 5.1 V |
| R10, R12, R18, R19 | 4 | 10k | Resistor 0603 1% |  | R_0603_1608Metric | Q3 gate pull-up |
| R13 | 1 | 330R | Resistor 0603 1% |  | R_0603_1608Metric | LED data series termination |
| R20, R21 | 2 | 12k | Resistor 0603 1% |  | R_0603_1608Metric |  |
| SW1 | 1 | POWER | Slide switch SPDT right-angle THT (power) | C&K OS102011MA1QN1 | SW_Slide_SPDT_Angled_CK_OS102011MA1Q | ON = SYS_EN high; only switches the LDO enable (tiny current) |
| SW2 | 1 | RESET | Tactile switch 3x6x2.5 mm SMD | TL3342 / TS-1187A | SW_SPST_TL3342 |  |
| SW3 | 1 | BOOT | Tactile switch 3x6x2.5 mm SMD | TL3342 / TS-1187A | SW_SPST_TL3342 |  |
| U1 | 1 | ESP32-WROOM-32E-N4 | ESP32-WROOM-32E-N4 WiFi/BT module, 4 MB flash | ESP32-WROOM-32E-N4 | ESP32-WROOM-32 |  |
| U2 | 1 | TP4056 | 1 A linear Li-ion charger, ESOP-8 | TP4056 | SOIC-8-1EP_3.9x4.9mm_P1.27mm_EP2.29x3mm |  |
| U3 | 1 | DW01A | 1S Li-ion protection IC | DW01A-G | SOT-23-6 |  |
| U4 | 1 | MT3608 | Boost converter 2-24 V in, 1.2 MHz, 4 A switch | MT3608 | SOT-23-6 |  |
| U5 | 1 | AP2112K-3.3 | LDO 3.3 V 600 mA low dropout | AP2112K-3.3TRG1 | SOT-23-5 |  |
| U6 | 1 | CH340C | USB-UART bridge, internal oscillator | CH340C | SOIC-16_3.9x9.9mm_P1.27mm |  |
| U7 | 1 | 74AHCT1G125 | Single bus buffer, 3.3->5 V level shift for LED data | SN74AHCT1G125DBVR | SOT-23-5 |  |
| U8 | 1 | USBLC6-2SC6 | USB ESD protection (optional) | USBLC6-2SC6 | SOT-23-6 | optional ESD protection |

## Per-component pin connections

### BT1 - 18650 (18650 PCB-mount holder)

| Pin | Name | Net |
|---|---|---|
| 1 | + | `BAT+` |
| 2 | - | `CELL-` |

### BT2 - 18650 (optional 2nd cell) (18650 PCB-mount holder)

| Pin | Name | Net |
|---|---|---|
| 1 | + | `BAT+` |
| 2 | - | `CELL-` |

### C1 - 10uF 10V (Capacitor 0805 X5R)

| Pin | Name | Net |
|---|---|---|
| 1 | 1 | `VBUS` |
| 2 | 2 | `GND` |

### C2 - 10uF 10V (Capacitor 0805 X5R)

| Pin | Name | Net |
|---|---|---|
| 1 | 1 | `BAT+` |
| 2 | 2 | `GND` |

### C3 - 100nF (Capacitor 0603 X7R)

| Pin | Name | Net |
|---|---|---|
| 1 | 1 | `DW01_VCC` |
| 2 | 2 | `CELL-` |

### C4 - 22uF 10V (Capacitor 0805 X5R)

| Pin | Name | Net |
|---|---|---|
| 1 | 1 | `VSYS` |
| 2 | 2 | `GND` |

### C5 - 22uF 10V (Capacitor 0805 X5R)

| Pin | Name | Net |
|---|---|---|
| 1 | 1 | `VSYS` |
| 2 | 2 | `GND` |

### C6 - 22uF 10V (Capacitor 0805 X5R)

| Pin | Name | Net |
|---|---|---|
| 1 | 1 | `+5V` |
| 2 | 2 | `GND` |

### C7 - 22uF 10V (Capacitor 0805 X5R)

| Pin | Name | Net |
|---|---|---|
| 1 | 1 | `+5V` |
| 2 | 2 | `GND` |

### C8 - 100uF 6.3V (Electrolytic / polymer cap SMD 6.3x5.4)

| Pin | Name | Net |
|---|---|---|
| 1 | + | `VLED` |
| 2 | - | `GND` |

### C9 - 1uF (Capacitor 0603 X7R)

| Pin | Name | Net |
|---|---|---|
| 1 | 1 | `VSYS` |
| 2 | 2 | `GND` |

### C10 - 10uF 10V (Capacitor 0805 X5R)

| Pin | Name | Net |
|---|---|---|
| 1 | 1 | `3V3` |
| 2 | 2 | `GND` |

### C11 - 100nF (Capacitor 0603 X7R)

| Pin | Name | Net |
|---|---|---|
| 1 | 1 | `3V3` |
| 2 | 2 | `GND` |

### C12 - 10uF 10V (Capacitor 0805 X5R)

| Pin | Name | Net |
|---|---|---|
| 1 | 1 | `3V3` |
| 2 | 2 | `GND` |

### C13 - 1uF (Capacitor 0603 X7R)

| Pin | Name | Net |
|---|---|---|
| 1 | 1 | `EN` |
| 2 | 2 | `GND` |

### C14 - 100nF (Capacitor 0603 X7R)

| Pin | Name | Net |
|---|---|---|
| 1 | 1 | `3V3` |
| 2 | 2 | `GND` |

### C15 - 100nF (Capacitor 0603 X7R)

| Pin | Name | Net |
|---|---|---|
| 1 | 1 | `+5V` |
| 2 | 2 | `GND` |

### C16 - 100nF (Capacitor 0603 X7R)

| Pin | Name | Net |
|---|---|---|
| 1 | 1 | `VBAT_SENSE` |
| 2 | 2 | `GND` |

### C17 - 100nF (Capacitor 0603 X7R)

| Pin | Name | Net |
|---|---|---|
| 1 | 1 | `VBUS_DET` |
| 2 | 2 | `GND` |

### D1 - SS34 (Schottky diode SMA)

| Pin | Name | Net |
|---|---|---|
| 1 | K | `VSYS` |
| 2 | A | `VBUS` |

### D2 - SS34 (Schottky diode SMA)

| Pin | Name | Net |
|---|---|---|
| 1 | K | `+5V` |
| 2 | A | `BOOST_SW` |

### D3 - RED (LED 0603)

| Pin | Name | Net |
|---|---|---|
| 1 | K | `CHRG` |
| 2 | A | `N$2` |

### D4 - GREEN (LED 0603)

| Pin | Name | Net |
|---|---|---|
| 1 | K | `STDBY` |
| 2 | A | `N$3` |

### J1 - USB-C 16P (USB-C receptacle 16 pin, top mount)

| Pin | Name | Net |
|---|---|---|
| A1 | GND | `GND` |
| A4 | VBUS | `VBUS` |
| A5 | CC1 | `CC1` |
| A6 | D+ | `USB_D+` |
| A7 | D- | `USB_D-` |
| A8 | SBU1 | `-` |
| A9 | VBUS | `VBUS` |
| B1 | GND | `GND` |
| B4 | VBUS | `VBUS` |
| B5 | CC2 | `CC2` |
| B6 | D+ | `USB_D+` |
| B7 | D- | `USB_D-` |
| B8 | SBU2 | `-` |
| B9 | VBUS | `VBUS` |
| S1 | SHIELD | `GND` |
| A12 | GND | `GND` |
| B12 | GND | `GND` |

### J2 - LED RING (JST PH 2.0 mm 3 pin)

| Pin | Name | Net |
|---|---|---|
| 1 | 1 | `VLED` |
| 2 | 2 | `GND` |
| 3 | 3 | `LED_DOUT` |

### J3 - TOUCH (JST PH 2.0 mm 2 pin)

| Pin | Name | Net |
|---|---|---|
| 1 | 1 | `TOUCH_PAD` |
| 2 | 2 | `GND` |

### J4 - EXP (Pin header 1x6 2.54 mm (expansion))

| Pin | Name | Net |
|---|---|---|
| 1 | 1 | `3V3` |
| 2 | 2 | `GND` |
| 3 | 3 | `IO25` |
| 4 | 4 | `IO26` |
| 5 | 5 | `IO32` |
| 6 | 6 | `IO33` |

### J5 - BAT ALT (JST PH 2.0 mm 2 pin)

| Pin | Name | Net |
|---|---|---|
| 1 | 1 | `BAT+` |
| 2 | 2 | `CELL-` |

### L1 - 4.7uH 4A (Power inductor 6x6 mm shielded)

| Pin | Name | Net |
|---|---|---|
| 1 | 1 | `VSYS` |
| 2 | 2 | `BOOST_SW` |

### Q1 - FS8205A (Dual N-MOSFET common drain, 20 V, 6 A (battery protection))

| Pin | Name | Net |
|---|---|---|
| 1 | S1 | `CELL-` |
| 2 | G1 | `DW01_OD` |
| 3 | S2 | `GND` |
| 4 | G2 | `DW01_OC` |
| 5 | D2 | `PROT_FET_D` |
| 6 | D2 | `PROT_FET_D` |
| 7 | D1 | `PROT_FET_D` |
| 8 | D1 | `PROT_FET_D` |

### Q2 - AO4407A (P-MOSFET -30 V 12 A 12 mOhm (load sharing))

| Pin | Name | Net |
|---|---|---|
| 1 | S | `VSYS` |
| 2 | S | `VSYS` |
| 3 | S | `VSYS` |
| 4 | G | `VBUS` |
| 5 | D | `BAT+` |
| 6 | D | `BAT+` |
| 7 | D | `BAT+` |
| 8 | D | `BAT+` |

### Q3 - AO3401A (P-MOSFET -30 V 4 A (LED rail switch))

| Pin | Name | Net |
|---|---|---|
| 1 | G | `nLED_EN` |
| 2 | S | `+5V` |
| 3 | D | `VLED` |

### Q4 - 2N7002 (N-MOSFET 60 V 300 mA)

| Pin | Name | Net |
|---|---|---|
| 1 | G | `LED_EN` |
| 2 | S | `GND` |
| 3 | D | `nLED_EN` |

### Q5 - MMBT3904 (NPN transistor (auto-reset))

| Pin | Name | Net |
|---|---|---|
| 1 | B | `DTR_B` |
| 2 | E | `RTS` |
| 3 | C | `EN` |

### Q6 - MMBT3904 (NPN transistor (auto-reset))

| Pin | Name | Net |
|---|---|---|
| 1 | B | `RTS_B` |
| 2 | E | `DTR` |
| 3 | C | `IO0` |

### R1 - 5.1k (Resistor 0603 1%)

| Pin | Name | Net |
|---|---|---|
| 1 | 1 | `CC1` |
| 2 | 2 | `GND` |

### R2 - 5.1k (Resistor 0603 1%)

| Pin | Name | Net |
|---|---|---|
| 1 | 1 | `CC2` |
| 2 | 2 | `GND` |

### R3 - 1.2k (Resistor 0603 1%)

| Pin | Name | Net |
|---|---|---|
| 1 | 1 | `N$1` |
| 2 | 2 | `GND` |

### R4 - 1k (Resistor 0603 1%)

| Pin | Name | Net |
|---|---|---|
| 1 | 1 | `VBUS` |
| 2 | 2 | `N$2` |

### R5 - 1k (Resistor 0603 1%)

| Pin | Name | Net |
|---|---|---|
| 1 | 1 | `VBUS` |
| 2 | 2 | `N$3` |

### R6 - 100R (Resistor 0603 1%)

| Pin | Name | Net |
|---|---|---|
| 1 | 1 | `BAT+` |
| 2 | 2 | `DW01_VCC` |

### R7 - 1k (Resistor 0603 1%)

| Pin | Name | Net |
|---|---|---|
| 1 | 1 | `GND` |
| 2 | 2 | `DW01_CS` |

### R8 - 100k (Resistor 0603 1%)

| Pin | Name | Net |
|---|---|---|
| 1 | 1 | `VBUS` |
| 2 | 2 | `GND` |

### R9 - 75k (Resistor 0603 1%)

| Pin | Name | Net |
|---|---|---|
| 1 | 1 | `+5V` |
| 2 | 2 | `BOOST_FB` |

### R10 - 10k (Resistor 0603 1%)

| Pin | Name | Net |
|---|---|---|
| 1 | 1 | `BOOST_FB` |
| 2 | 2 | `GND` |

### R11 - 100k (Resistor 0603 1%)

| Pin | Name | Net |
|---|---|---|
| 1 | 1 | `LED_EN` |
| 2 | 2 | `GND` |

### R12 - 10k (Resistor 0603 1%)

| Pin | Name | Net |
|---|---|---|
| 1 | 1 | `+5V` |
| 2 | 2 | `nLED_EN` |

### R13 - 330R (Resistor 0603 1%)

| Pin | Name | Net |
|---|---|---|
| 1 | 1 | `LED_DATA_5V` |
| 2 | 2 | `LED_DOUT` |

### R14 - 100k (Resistor 0603 1%)

| Pin | Name | Net |
|---|---|---|
| 1 | 1 | `BAT+` |
| 2 | 2 | `VBAT_SENSE` |

### R15 - 100k (Resistor 0603 1%)

| Pin | Name | Net |
|---|---|---|
| 1 | 1 | `VBAT_SENSE` |
| 2 | 2 | `GND` |

### R16 - 100k (Resistor 0603 1%)

| Pin | Name | Net |
|---|---|---|
| 1 | 1 | `VBUS` |
| 2 | 2 | `VBUS_DET` |

### R17 - 100k (Resistor 0603 1%)

| Pin | Name | Net |
|---|---|---|
| 1 | 1 | `VBUS_DET` |
| 2 | 2 | `GND` |

### R18 - 10k (Resistor 0603 1%)

| Pin | Name | Net |
|---|---|---|
| 1 | 1 | `3V3` |
| 2 | 2 | `EN` |

### R19 - 10k (Resistor 0603 1%)

| Pin | Name | Net |
|---|---|---|
| 1 | 1 | `3V3` |
| 2 | 2 | `IO0` |

### R20 - 12k (Resistor 0603 1%)

| Pin | Name | Net |
|---|---|---|
| 1 | 1 | `DTR` |
| 2 | 2 | `DTR_B` |

### R21 - 12k (Resistor 0603 1%)

| Pin | Name | Net |
|---|---|---|
| 1 | 1 | `RTS` |
| 2 | 2 | `RTS_B` |

### R22 - 1k (Resistor 0603 1%)

| Pin | Name | Net |
|---|---|---|
| 1 | 1 | `TOUCH` |
| 2 | 2 | `TOUCH_PAD` |

### SW1 - POWER (Slide switch SPDT right-angle THT (power))

| Pin | Name | Net |
|---|---|---|
| 1 | 1 | `VSYS` |
| 2 | COM | `SYS_EN` |
| 3 | 3 | `GND` |

### SW2 - RESET (Tactile switch 3x6x2.5 mm SMD)

| Pin | Name | Net |
|---|---|---|
| 1 | 1 | `EN` |
| 2 | 2 | `GND` |

### SW3 - BOOT (Tactile switch 3x6x2.5 mm SMD)

| Pin | Name | Net |
|---|---|---|
| 1 | 1 | `IO0` |
| 2 | 2 | `GND` |

### U1 - ESP32-WROOM-32E-N4 (ESP32-WROOM-32E-N4 WiFi/BT module, 4 MB flash)

| Pin | Name | Net |
|---|---|---|
| 1 | GND | `GND` |
| 2 | 3V3 | `3V3` |
| 3 | EN | `EN` |
| 4 | SENSOR_VP | `(no connect)` |
| 5 | SENSOR_VN | `(no connect)` |
| 6 | IO34 | `VBUS_DET` |
| 7 | IO35 | `VBAT_SENSE` |
| 8 | IO32 | `IO32` |
| 9 | IO33 | `IO33` |
| 10 | IO25 | `IO25` |
| 11 | IO26 | `IO26` |
| 12 | IO27 | `(no connect)` |
| 13 | IO14 | `(no connect)` |
| 14 | IO12 | `(no connect)` |
| 15 | GND | `GND` |
| 16 | IO13 | `(no connect)` |
| 17 | NC | `-` |
| 18 | NC | `-` |
| 19 | NC | `-` |
| 20 | NC | `-` |
| 21 | NC | `-` |
| 22 | NC | `-` |
| 23 | IO15 | `(no connect)` |
| 24 | IO2 | `LED_DATA` |
| 25 | IO0 | `IO0` |
| 26 | IO4 | `TOUCH` |
| 27 | IO16 | `LED_EN` |
| 28 | IO17 | `(no connect)` |
| 29 | IO5 | `(no connect)` |
| 30 | IO18 | `(no connect)` |
| 31 | IO19 | `(no connect)` |
| 32 | NC | `-` |
| 33 | IO21 | `(no connect)` |
| 34 | RXD0 | `U0RXD` |
| 35 | TXD0 | `U0TXD` |
| 36 | IO22 | `(no connect)` |
| 37 | IO23 | `(no connect)` |
| 38 | GND | `GND` |
| 39 | GND | `GND` |

### U2 - TP4056 (1 A linear Li-ion charger, ESOP-8)

| Pin | Name | Net |
|---|---|---|
| 1 | TEMP | `GND` |
| 2 | PROG | `N$1` |
| 3 | GND | `GND` |
| 4 | VCC | `VBUS` |
| 5 | BAT | `BAT+` |
| 6 | STDBY | `STDBY` |
| 7 | CHRG | `CHRG` |
| 8 | CE | `VBUS` |
| 9 | EP | `GND` |

### U3 - DW01A (1S Li-ion protection IC)

| Pin | Name | Net |
|---|---|---|
| 1 | OD | `DW01_OD` |
| 2 | CS | `DW01_CS` |
| 3 | OC | `DW01_OC` |
| 4 | TD | `CELL-` |
| 5 | VCC | `DW01_VCC` |
| 6 | GND | `CELL-` |

### U4 - MT3608 (Boost converter 2-24 V in, 1.2 MHz, 4 A switch)

| Pin | Name | Net |
|---|---|---|
| 1 | SW | `BOOST_SW` |
| 2 | GND | `GND` |
| 3 | FB | `BOOST_FB` |
| 4 | EN | `LED_EN` |
| 5 | IN | `VSYS` |
| 6 | NC | `-` |

### U5 - AP2112K-3.3 (LDO 3.3 V 600 mA low dropout)

| Pin | Name | Net |
|---|---|---|
| 1 | VIN | `VSYS` |
| 2 | GND | `GND` |
| 3 | EN | `SYS_EN` |
| 4 | NC | `-` |
| 5 | VOUT | `3V3` |

### U6 - CH340C (USB-UART bridge, internal oscillator)

| Pin | Name | Net |
|---|---|---|
| 1 | GND | `GND` |
| 2 | TXD | `U0RXD` |
| 3 | RXD | `U0TXD` |
| 4 | V3 | `3V3` |
| 5 | UD+ | `USB_D+` |
| 6 | UD- | `USB_D-` |
| 7 | XI | `-` |
| 8 | XO | `-` |
| 9 | CTS# | `-` |
| 10 | DSR# | `-` |
| 11 | RI# | `-` |
| 12 | DCD# | `-` |
| 13 | DTR# | `DTR` |
| 14 | RTS# | `RTS` |
| 15 | R232 | `GND` |
| 16 | VCC | `3V3` |

### U7 - 74AHCT1G125 (Single bus buffer, 3.3->5 V level shift for LED data)

| Pin | Name | Net |
|---|---|---|
| 1 | OE# | `nLED_EN` |
| 2 | A | `LED_DATA` |
| 3 | GND | `GND` |
| 4 | Y | `LED_DATA_5V` |
| 5 | VCC | `+5V` |

### U8 - USBLC6-2SC6 (USB ESD protection (optional))

| Pin | Name | Net |
|---|---|---|
| 1 | IO1 | `USB_D+` |
| 2 | GND | `GND` |
| 3 | IO2 | `USB_D-` |
| 4 | IO2 | `USB_D-` |
| 5 | VBUS | `VBUS` |
| 6 | IO1 | `USB_D+` |

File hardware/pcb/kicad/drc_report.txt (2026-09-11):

** Drc report for /home/user/TableLight/hardware/pcb/kicad/tablelight_routed.kicad_pcb **
** Created on 2026-09-11 10:28:53 **

** Found 117 DRC violations **
[silk_overlap]: Silkscreen overlap
    Rule: board setup constraints silk; Severity: warning
    @(33.0700 mm, 28.5000 mm): Reference 'R10'
    @(33.0225 mm, 28.7373 mm): Line on F.Silkscreen
[silk_overlap]: Silkscreen overlap
    Rule: board setup constraints silk; Severity: warning
    @(30.0000 mm, -32.4000 mm): Reference 'U7'
    @(29.8594 mm, -32.9900 mm): Line on F.Silkscreen
[silk_overlap]: Silkscreen overlap
    Rule: board setup constraints silk; Severity: warning
    @(0.0000 mm, 26.6000 mm): PCB Text 'github.com/jonny190/TableLight' on F.Silkscreen
    @(-2.7000 mm, -2.4650 mm): Polygon on F.Silkscreen
[silk_overlap]: Silkscreen overlap
    Rule: board setup constraints silk; Severity: warning
    @(18.5700 mm, 29.0000 mm): Reference 'R8'
    @(18.2350 mm, 29.7613 mm): Line on F.Silkscreen
[silk_overlap]: Silkscreen overlap
    Rule: board setup constraints silk; Severity: warning
    @(5.5000 mm, 43.5700 mm): Reference 'R2'
    @(5.2627 mm, 43.5225 mm): Line on F.Silkscreen
[silk_overlap]: Silkscreen overlap
    Rule: board setup constraints silk; Severity: warning
    @(-26.4300 mm, 28.0000 mm): Reference 'R7'
    @(-26.9900 mm, 28.1406 mm): Line on F.Silkscreen
[silk_overlap]: Silkscreen overlap
    Rule: board setup constraints silk; Severity: warning
    @(-29.4775 mm, 28.2373 mm): Line on F.Silkscreen
    @(-28.9300 mm, 28.0000 mm): Reference 'C3'
[silk_overlap]: Silkscreen overlap
    Rule: board setup constraints silk; Severity: warning
    @(-21.5000 mm, 41.0600 mm): Line on F.Silkscreen
    @(-21.5000 mm, 41.1000 mm): Reference 'Q5'
[silk_overlap]: Silkscreen overlap
    Rule: board setup constraints silk; Severity: warning
    @(-21.5000 mm, 41.1000 mm): Reference 'Q5'
    @(-21.5000 mm, 41.0600 mm): Line on F.Silkscreen
[silk_overlap]: Silkscreen overlap
    Rule: board setup constraints silk; Severity: warning
    @(12.5000 mm, 32.5600 mm): Line on F.Silkscreen
    @(12.5000 mm, 32.5000 mm): Reference 'D1'
[silk_overlap]: Silkscreen overlap
    Rule: board setup constraints silk; Severity: warning
    @(23.5000 mm, 34.5600 mm): Line on F.Silkscreen
    @(23.5000 mm, 35.0700 mm): Reference 'R12'
[silk_overlap]: Silkscreen overlap
    Rule: board setup constraints silk; Severity: warning
    @(23.5000 mm, 34.5600 mm): Line on F.Silkscreen
    @(23.5000 mm, 35.0700 mm): Reference 'R12'
[silk_overlap]: Silkscreen overlap
    Rule: board setup constraints silk; Severity: warning
    @(28.0000 mm, 33.3200 mm): Reference 'C7'
    @(27.7387 mm, 33.7350 mm): Line on F.Silkscreen
[silk_overlap]: Silkscreen overlap
    Rule: board setup constraints silk; Severity: warning
    @(19.0000 mm, 34.5600 mm): Line on F.Silkscreen
    @(19.0000 mm, 35.0700 mm): Reference 'R11'
[silk_overlap]: Silkscreen overlap
    Rule: board setup constraints silk; Severity: warning
    @(19.0000 mm, 35.0700 mm): Reference 'R11'
    @(19.0000 mm, 34.5600 mm): Line on F.Silkscreen
[silk_overlap]: Silkscreen overlap
    Rule: board setup constraints silk; Severity: warning
    @(12.5000 mm, 32.5000 mm): Reference 'D1'
    @(12.5000 mm, 32.5600 mm): Line on F.Silkscreen
[silk_overlap]: Silkscreen overlap
    Rule: board setup constraints silk; Severity: warning
    @(-19.3685 mm, 48.2621 mm): Reference 'D4'
    @(-20.3765 mm, 47.9349 mm): Line on F.Silkscreen
[silk_over_copper]: Silkscreen clipped by solder mask
    Local override; Severity: warning
    @(-46.0000 mm, 14.4000 mm): PCB Text '+' on F.Silkscreen
[silk_over_copper]: Silkscreen clipped by solder mask
    Local override; Severity: warning
    @(46.0000 mm, 14.4000 mm): PCB Text '-' on F.Silkscreen
[silk_over_copper]: Silkscreen clipped by solder mask
    Local override; Severity: warning
    @(-32.0000 mm, -26.8000 mm): PCB Text 'TableLight v1.0' on F.Silkscreen
[silk_over_copper]: Silkscreen clipped by solder mask
    Local override; Severity: warning
    @(46.0000 mm, -14.4000 mm): PCB Text '-' on F.Silkscreen
[silk_over_copper]: Silkscreen clipped by solder mask
    Local override; Severity: warning
    @(-40.5000 mm, 17.0000 mm): PCB Text 'BAT ALT' on F.Silkscreen
[silk_over_copper]: Silkscreen clipped by solder mask
    Local override; Severity: warning
    @(30.0000 mm, -32.4000 mm): Reference 'U7'
[silk_over_copper]: Silkscreen clipped by solder mask
    Local override; Severity: warning
    @(-9.9300 mm, 37.5000 mm): Reference 'C14'
[silk_over_copper]: Silkscreen clipped by solder mask
    Local override; Severity: warning
    @(-26.4300 mm, 28.0000 mm): Reference 'R7'
[silk_over_copper]: Silkscreen clipped by solder mask
    Local override; Severity: warning
    @(5.5000 mm, 43.5700 mm): Reference 'R2'
[silk_over_copper]: Silkscreen clipped by solder mask
    Local override; Severity: warning
    @(-28.9300 mm, 40.0000 mm): Reference 'R20'
[silk_over_copper]: Silkscreen clipped by solder mask
    Local override; Severity: warning
    @(28.0000 mm, 33.3200 mm): Reference 'C7'
[silk_over_copper]: Silkscreen clipped by solder mask
    Local override; Severity: warning
    @(42.7000 mm, 16.0000 mm): Reference 'L1'
[silk_over_copper]: Silkscreen clipped by solder mask
    Local override; Severity: warning
    @(44.2000 mm, 19.1000 mm): Line on F.Silkscreen
[silk_over_copper]: Silkscreen clipped by solder mask
    Local override; Severity: warning
    @(50.4000 mm, 19.1000 mm): Line on F.Silkscreen
[silk_over_copper]: Silkscreen clipped by solder mask
    Local override; Severity: warning
    @(44.2000 mm, 12.9000 mm): Line on F.Silkscreen
[silk_over_copper]: Silkscreen clipped by solder mask
    Local override; Severity: warning
    @(50.4000 mm, 12.9000 mm): Line on F.Silkscreen
[silk_over_copper]: Silkscreen clipped by solder mask
    Local override; Severity: warning
    @(43.1500 mm, -12.0000 mm): Reference 'C8'
[silk_over_copper]: Silkscreen clipped by solder mask
    Local override; Severity: warning
    @(33.0700 mm, 28.5000 mm): Reference 'R10'
[silk_over_copper]: Silkscreen clipped by solder mask
    Local override; Severity: warning
    @(-23.4300 mm, -36.5000 mm): Reference 'C17'
[silk_over_copper]: Silkscreen clipped by solder mask
    Local override; Severity: warning
    @(-28.9300 mm, 28.0000 mm): Reference 'C3'
[silk_over_copper]: Silkscreen clipped by solder mask
    Local override; Severity: warning
    @(19.0000 mm, 30.6000 mm): Reference 'Q4'
[silk_over_copper]: Silkscreen clipped by solder mask
    Local override; Severity: warning
    @(18.5700 mm, 29.0000 mm): Reference 'R8'
[silk_over_copper]: Silkscreen clipped by solder mask
    Local override; Severity: warning
    @(-21.5000 mm, 41.1000 mm): Reference 'Q5'
[silk_over_copper]: Silkscreen clipped by solder mask
    Local override; Severity: warning
    @(15.8200 mm, 29.5000 mm): Reference 'C5'
[silk_over_copper]: Silkscreen clipped by solder mask
    Local override; Severity: warning
    @(-23.4300 mm, -40.0000 mm): Reference 'C16'
[lib_footprint_issues]: The current configuration does not include the library ''.
    Local override; Severity: warning
    @(-35.3553 mm, -35.3553 mm): Footprint H3
[lib_footprint_issues]: The current configuration does not include the library ''.
    Local override; Severity: warning
    @(-48.5000 mm, -4.0000 mm): Footprint J3
[lib_footprint_issues]: The current configuration does not include the library ''.
    Local override; Severity: warning
    @(30.0000 mm, -30.0000 mm): Footprint U7
[lib_footprint_issues]: The current configuration does not include the library ''.
    Local override; Severity: warning
    @(-41.5000 mm, 28.5000 mm): Footprint Q1
[lib_footprint_issues]: The current configuration does not include the library ''.
    Local override; Severity: warning
    @(-8.5000 mm, 37.5000 mm): Footprint C14
[lib_footprint_issues]: The current configuration does not include the library ''.
    Local override; Severity: warning
    @(-16.0000 mm, -40.0000 mm): Footprint R14
[lib_footprint_issues]: The current configuration does not include the library ''.
    Local override; Severity: warning
    @(12.5000 mm, 35.0000 mm): Footprint D1
[lib_footprint_issues]: The current configuration does not include the library ''.
    Local override; Severity: warning
    @(-21.5000 mm, 39.5000 mm): Footprint Q6
[lib_footprint_issues]: The current configuration does not include the library ''.
    Local override; Severity: warning
    @(-15.7599 mm, 48.5039 mm): Footprint D3
[lib_footprint_issues]: The current configuration does not include the library ''.
    Local override; Severity: warning
    @(12.5000 mm, -33.5000 mm): Footprint R22
[lib_footprint_issues]: The current configuration does not include the library ''.
    Local override; Severity: warning
    @(-29.0000 mm, 42.5000 mm): Footprint R4
[lib_footprint_issues]: The current configuration does not include the library ''.
    Local override; Severity: warning
    @(45.7000 mm, 24.0000 mm): Footprint U4
[lib_footprint_issues]: The current configuration does not include the library ''.
    Local override; Severity: warning
    @(-27.0000 mm, -37.0000 mm): Footprint SW2
[lib_footprint_issues]: The current configuration does not include the library ''.
    Local override; Severity: warning
    @(35.3553 mm, 35.3553 mm): Footprint H1
[lib_footprint_issues]: The current configuration does not include the library ''.
    Local override; Severity: warning
    @(12.5000 mm, 30.0000 mm): Footprint Q2
[lib_footprint_issues]: The current configuration does not include the library ''.
    Local override; Severity: warning
    @(0.0000 mm, 14.4000 mm): Footprint BT2
[lib_footprint_issues]: The current configuration does not include the library ''.
    Local override; Severity: warning
    @(-25.0000 mm, 28.0000 mm): Footprint R7
[lib_footprint_issues]: The current configuration does not include the library ''.
    Local override; Severity: warning
    @(-12.5000 mm, -39.0000 mm): Footprint R18
[lib_footprint_issues]: The current configuration does not include the library ''.
    Local override; Severity: warning
    @(12.5000 mm, -29.5000 mm): Footprint R19
[lib_footprint_issues]: The current configuration does not include the library ''.
    Local override; Severity: warning
    @(23.5000 mm, 33.0000 mm): Footprint Q3
[lib_footprint_issues]: The current configuration does not include the library ''.
    Local override; Severity: warning
    @(28.0000 mm, 33.0000 mm): Footprint C6
[lib_footprint_issues]: The current configuration does not include the library ''.
    Local override; Severity: warning
    @(5.5000 mm, 45.0000 mm): Footprint R2
[lib_footprint_issues]: The current configuration does not include the library ''.
    Local override; Severity: warning
    @(-27.5000 mm, 40.0000 mm): Footprint R20
[lib_footprint_issues]: The current configuration does not include the library ''.
    Local override; Severity: warning
    @(-12.5000 mm, -35.5000 mm): Footprint C13
[lib_footprint_issues]: The current configuration does not include the library ''.
    Local override; Severity: warning
    @(32.5000 mm, 28.5000 mm): Footprint R9
[lib_footprint_issues]: The current configuration does not include the library ''.
    Local override; Severity: warning
    @(0.0000 mm, -14.4000 mm): Footprint BT1
[lib_footprint_issues]: The current configuration does not include the library ''.
    Local override; Severity: warning
    @(23.5000 mm, 36.5000 mm): Footprint R12
[lib_footprint_issues]: The current configuration does not include the library ''.
    Local override; Severity: warning
    @(42.0000 mm, 31.5000 mm): Footprint C4
[lib_footprint_issues]: The current configuration does not include the library ''.
    Local override; Severity: warning
    @(-13.5000 mm, 42.0000 mm): Footprint U6
[lib_footprint_issues]: The current configuration does not include the library ''.
    Local override; Severity: warning
    @(9.5000 mm, 47.0000 mm): Footprint C1
[lib_footprint_issues]: The current configuration does not include the library ''.
    Local override; Severity: warning
    @(28.0000 mm, 35.0000 mm): Footprint C7
[lib_footprint_issues]: The current configuration does not include the library ''.
    Local override; Severity: warning
    @(-20.5000 mm, -30.0000 mm): Footprint J4
[lib_footprint_issues]: The current configuration does not include the library ''.
    Local override; Severity: warning
    @(-40.0000 mm, -28.5000 mm): Footprint SW3
[lib_footprint_issues]: The current configuration does not include the library ''.
    Local override; Severity: warning
    @(-31.5000 mm, 40.5000 mm): Footprint R5
[lib_footprint_issues]: The current configuration does not include the library ''.
    Local override; Severity: warning
    @(34.5000 mm, -30.0000 mm): Footprint R13
[lib_footprint_issues]: The current configuration does not include the library ''.
    Local override; Severity: warning
    @(20.0000 mm, -33.0000 mm): Footprint U5
[lib_footprint_issues]: The current configuration does not include the library ''.
    Local override; Severity: warning
    @(47.3000 mm, 16.0000 mm): Footprint L1
[lib_footprint_issues]: The current configuration does not include the library ''.
    Local override; Severity: warning
    @(-19.9273 mm, 46.9457 mm): Footprint D4
[lib_footprint_issues]: The current configuration does not include the library ''.
    Local override; Severity: warning
    @(47.5000 mm, -12.0000 mm): Footprint C8
[lib_footprint_issues]: The current configuration does not include the library ''.
    Local override; Severity: warning
    @(34.5000 mm, 28.5000 mm): Footprint R10
[lib_footprint_issues]: The current configuration does not include the library ''.
    Local override; Severity: warning
    @(-22.0000 mm, -36.5000 mm): Footprint C17
[lib_footprint_issues]: The current configuration does not include the library ''.
    Local override; Severity: warning
    @(-35.3553 mm, 35.3553 mm): Footprint H2
[lib_footprint_issues]: The current configuration does not include the library ''.
    Local override; Severity: warning
    @(-30.0000 mm, 28.0000 mm): Footprint R6
[lib_footprint_issues]: The current configuration does not include the library ''.
    Local override; Severity: warning
    @(-27.5000 mm, 28.0000 mm): Footprint C3
[lib_footprint_issues]: The current configuration does not include the library ''.
    Local override; Severity: warning
    @(15.0000 mm, 47.5000 mm): Footprint C2
[lib_footprint_issues]: The current configuration does not include the library ''.
    Local override; Severity: warning
    @(-12.5000 mm, -42.5000 mm): Footprint C12
[lib_footprint_issues]: The current configuration does not include the library ''.
    Local override; Severity: warning
    @(19.0000 mm, 33.0000 mm): Footprint Q4
[lib_footprint_issues]: The current configuration does not include the library ''.
    Local override; Severity: warning
    @(35.3553 mm, -35.3553 mm): Footprint H4
[lib_footprint_issues]: The current configuration does not include the library ''.
    Local override; Severity: warning
    @(5.5000 mm, 43.0000 mm): Footprint R1
[lib_footprint_issues]: The current configuration does not include the library ''.
    Local override; Severity: warning
    @(-34.0000 mm, 28.0000 mm): Footprint U3
[lib_footprint_issues]: The current configuration does not include the library ''.
    Local override; Severity: warning
    @(0.0000 mm, -38.0000 mm): Footprint U1
[lib_footprint_issues]: The current configuration does not include the library ''.
    Local override; Severity: warning
    @(0.0000 mm, 52.3000 mm): Footprint J1
[lib_footprint_issues]: The current configuration does not include the library ''.
    Local override; Severity: warning
    @(48.5000 mm, 4.0000 mm): Footprint J2
[lib_footprint_issues]: The current configuration does not include the library ''.
    Local override; Severity: warning
    @(-16.0000 mm, -36.5000 mm): Footprint R16
[lib_footprint_issues]: The current configuration does not include the library ''.
    Local override; Severity: warning
    @(16.5000 mm, -36.5000 mm): Footprint C9
[lib_footprint_issues]: The current configuration does not include the library ''.
    Local override; Severity: warning
    @(20.0000 mm, 29.0000 mm): Footprint R8
[lib_footprint_issues]: The current configuration does not include the library ''.
    Local override; Severity: warning
    @(-47.0000 mm, 17.0000 mm): Footprint J5
[lib_footprint_issues]: The current configuration does not include the library ''.
    Local override; Severity: warning
    @(22.8929 mm, 43.6518 mm): Footprint SW1
[lib_footprint_issues]: The current configuration does not include the library ''.
    Local override; Severity: warning
    @(40.0000 mm, 28.0000 mm): Footprint D2
[lib_footprint_issues]: The current configuration does not include the library ''.
    Local override; Severity: warning
    @(13.0000 mm, 42.0000 mm): Footprint U2
[lib_footprint_issues]: The current configuration does not include the library ''.
    Local override; Severity: warning
    @(8.0000 mm, 37.5000 mm): Footprint R3
[lib_footprint_issues]: The current configuration does not include the library ''.
    Local override; Severity: warning
    @(19.0000 mm, 36.5000 mm): Footprint R11
[lib_footprint_issues]: The current configuration does not include the library ''.
    Local override; Severity: warning
    @(-21.5000 mm, 43.5000 mm): Footprint Q5
[lib_footprint_issues]: The current configuration does not include the library ''.
    Local override; Severity: warning
    @(-19.0000 mm, -36.5000 mm): Footprint R17
[lib_footprint_issues]: The current configuration does not include the library ''.
    Local override; Severity: warning
    @(23.5000 mm, -36.5000 mm): Footprint C10
[lib_footprint_issues]: The current configuration does not include the library ''.
    Local override; Severity: warning
    @(-19.0000 mm, -40.0000 mm): Footprint R15
[lib_footprint_issues]: The current configuration does not include the library ''.
    Local override; Severity: warning
    @(-12.5000 mm, -46.0000 mm): Footprint C11
[lib_footprint_issues]: The current configuration does not include the library ''.
    Local override; Severity: warning
    @(17.5000 mm, 29.5000 mm): Footprint C5
[lib_footprint_issues]: The current configuration does not include the library ''.
    Local override; Severity: warning
    @(-6.0000 mm, 44.5000 mm): Footprint U8
[lib_footprint_issues]: The current configuration does not include the library ''.
    Local override; Severity: warning
    @(30.0000 mm, -33.5000 mm): Footprint C15
[lib_footprint_issues]: The current configuration does not include the library ''.
    Local override; Severity: warning
    @(-22.0000 mm, -40.0000 mm): Footprint C16
[lib_footprint_issues]: The current configuration does not include the library ''.
    Local override; Severity: warning
    @(-27.5000 mm, 37.0000 mm): Footprint R21
[silk_edge_clearance]: Silkscreen clipped by board edge
    Rule: board setup constraints silk; Severity: warning
    @(-4.0000 mm, 3.0000 mm): Line on Edge.Cuts
    @(0.0000 mm, 2.9000 mm): Reference 'BT2'
[silk_edge_clearance]: Silkscreen clipped by board edge
    Rule: board setup constraints silk; Severity: warning
    @(0.0000 mm, 0.0000 mm): Circle on Edge.Cuts
    @(-4.7000 mm, 54.3000 mm): Line on F.Silkscreen
[silk_edge_clearance]: Silkscreen clipped by board edge
    Rule: board setup constraints silk; Severity: warning
    @(0.0000 mm, 0.0000 mm): Circle on Edge.Cuts
    @(4.7000 mm, 54.3000 mm): Line on F.Silkscreen

** Found 0 unconnected pads **

** Found 0 Footprint errors **

** End of Report **

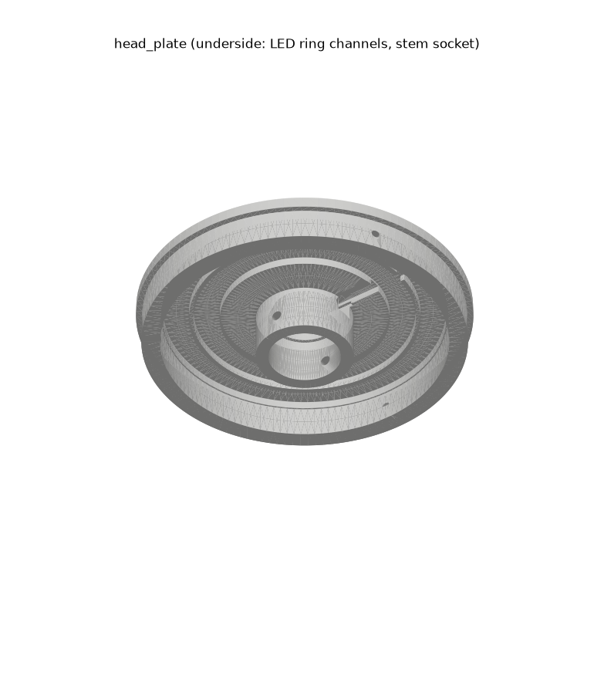
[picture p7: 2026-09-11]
docs/images/head_plate_bottom.png

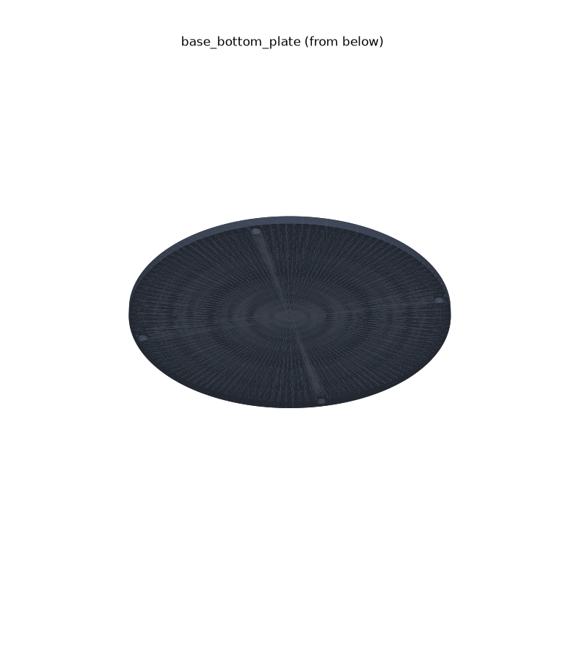
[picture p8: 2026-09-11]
docs/images/base_bottom_plate.png

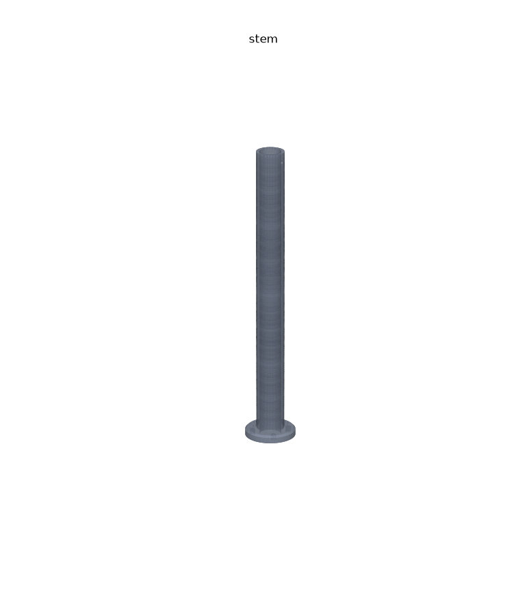
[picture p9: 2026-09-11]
docs/images/stem.png

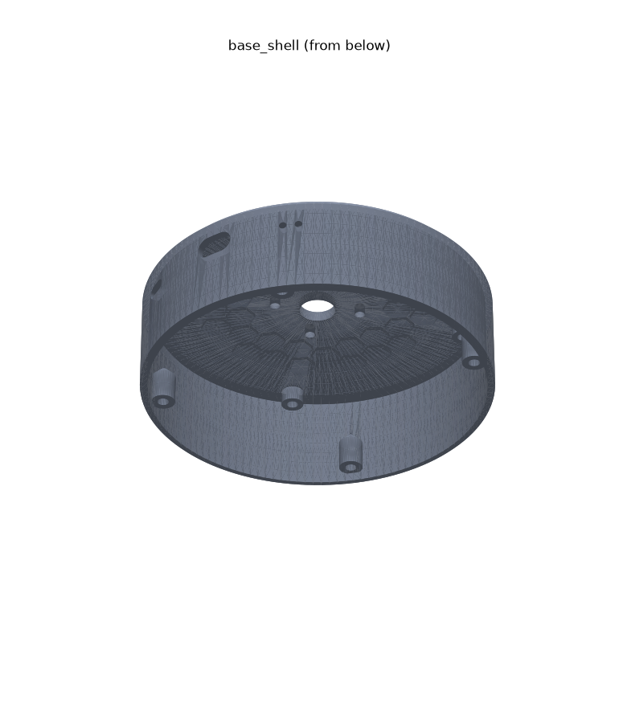
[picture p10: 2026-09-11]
docs/images/base_shell_bottom.png

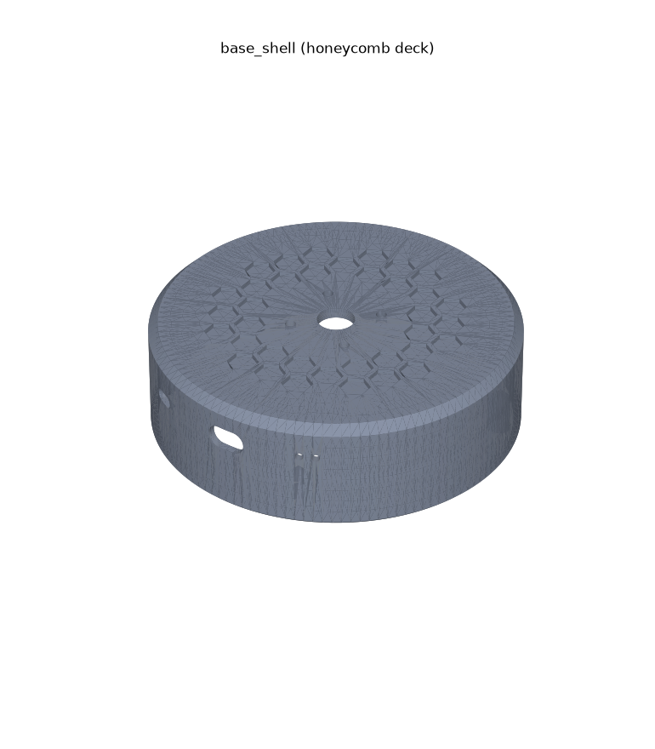
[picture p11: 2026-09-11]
docs/images/base_shell.png

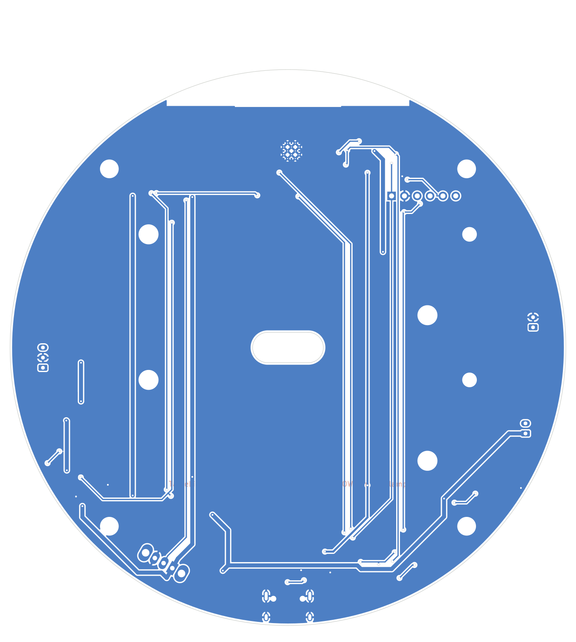
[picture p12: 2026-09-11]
docs/images/pcb_bottom.png

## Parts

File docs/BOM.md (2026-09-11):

# TableLight - Bill of Materials

Prices are rough 2026 hobby-quantity estimates (GBP) to help budgeting; check current suppliers.
The PCB component list with reference designators is generated in `hardware/pcb/bom_pcb.csv`.

## 1. Printed parts

| Part | File | Qty | Material | Approx. filament |
|---|---|---|---|---|
| Base shell (honeycomb disc) | `cad/stl/base_shell.stl` | 1 | PLA or PETG, opaque (black like the render) | 64 cm3 (~80 g) |
| Base bottom plate | `cad/stl/base_bottom_plate.stl` | 1 | same as shell | 30 cm3 (~37 g) |
| Stem | `cad/stl/stem.stl` | 1 | same as shell | 41 cm3 (~51 g) |
| Head plate (white top) | `cad/stl/head_plate.stl` | 1 | white PLA | 54 cm3 (~67 g) |
| Cone shade | `cad/stl/cone_shade.stl` | 1 | same as shell outside; white inside would be brighter (see PRINTING.md) | 73 cm3 (~90 g) |
| Head diffuser | `cad/stl/head_diffuser.stl` | 1 | natural / white translucent PLA or PETG | 10 cm3 (~12 g) |

Total ~340 g of filament (~£8).

## 2. Electronics - custom PCB path

| Item | Qty | Notes | Est. |
|---|---|---|---|
| TableLight controller PCB, Ø110 mm, 2 layer, 1.6 mm | 1 (min order 5) | upload `hardware/pcb/fab/tablelight-gerbers.zip` to PCBWay (form values in `hardware/pcb/fab/README.md`); optional SMD assembly with the BOM/CPL in the same folder | £5-£40 |
| PCB components (SMD + THT) | 1 set | full list in `hardware/pcb/bom_pcb.csv`; ~£12 as a one-off kit from LCSC/Mouser, key parts below | £12-£18 |
| - ESP32-WROOM-32E-N4 | 1 | WLED-supported module with native capacitive touch | |
| - TP4056 + DW01A + FS8205A | 1 each | charger + 1S protection | |
| - MT3608 + 4.7 uH / 4 A inductor + 2 x SS34 | 1 set | 5.1 V boost + load-share/boost diodes | |
| - AO4407A (SOIC-8) + AO3401A + 2N7002 | 1 each | load-share P-FET, LED rail switch, driver | |
| - AP2112K-3.3, CH340C, SN74AHCT1G125, USBLC6-2SC6 | 1 each | LDO, USB-UART, level shifter, ESD (ESD optional) | |
| - USB-C receptacle 16 pin (HRO TYPE-C-31-M-12) | 1 | top-mount | |
| - 18650 PCB holder (Keystone 1042 or BH-18650-PC) | 2 | fit one or both | |
| - C&K OS102011MA1QN1 slide switch, 2 x TL3342 tactile | 1 + 2 | power / RESET / BOOT | |
| - JST-PH 2.0 mm headers: 3 pin x1, 2 pin x2; 1x6 2.54 mm header | | LED, touch, alt. battery, expansion | |
| - passives 0603/0805, 100 uF 6.3 V SMD electrolytic, 2 x 0603 LEDs | | see CSV | |
| 18650 Li-ion cell, flat top, unprotected, e.g. Samsung INR18650-35E / LG MJ1 (3400-3500 mAh) | 1 or 2 | buy from a reputable seller; both cells identical if using two | £5-£7 each |
| LED ring, 24 x SK6812 RGBW (RGB + warm/neutral white) or WS2812B, 5 V, OD 86 mm / ID 72 mm | 1 | the common "24-bit WS2812B ring"; RGBW gives proper white for a lamp | £4-£7 |
| LED ring, 16 LED, OD 68 mm / ID 53 mm (or Adafruit NeoPixel Ring 24, OD 65.5 mm) | 0-1 | optional second ring in the inner channel (+16 LEDs, wired in series) | £3-£6 |
| Copper foil tape, self-adhesive, >= 20 mm wide | ~30 mm | touch pad disc Ø18 under the head plate | £3 (roll) |
| JST-PH pigtails: 3 pin x1, 2 pin x1 (300 mm leads) | 1 each | or crimp your own; leads must reach through the 236 mm stem | £2 |
| Silicone wire 26 AWG, 3 colours | ~1.5 m | ring-to-ring jumpers + touch wire | £3 |

## 3. Hardware

| Item | Qty | Where |
|---|---|---|
| M3 heat-set insert, Ø4.6 x 4-5.7 mm (hole Ø4.0) | 12 | 4 deck bosses (PCB), 4 stem flange, 4 shell bosses (bottom plate) |
| M3 x 6 mm pan/button head screw | 4 | PCB to deck bosses |
| M3 x 8 mm pan head screw | 8 | stem to deck (through the deck from below), bottom plate to shell |
| M3 x 6 mm button head screw, black | 5 | 3 x cone shade to head skirt (radial, self-tapping into Ø2.6 holes), 2 x head socket to stem |
| Rubber feet, self-adhesive, Ø10 x 3 mm | 4 | bottom plate recesses |
| Double-sided foam tape (1 mm) | small | LED ring(s) into the head channels |
| Kapton or electrical tape | small | over the touch pad foil / wire retention |

## 4. Tools

Soldering iron (heat-set insert tip helps), flush cutters, small Phillips driver, tweezers, USB-C cable
that carries data (not charge-only), a 5 V / 2 A+ USB-C supply.

## 5. Approximate total

Filament £8 + PCB and components £20-£55 + cells £5-£14 + rings/wire/foil £12-£20 + hardware £6
= **about £50-£100** for one lamp (the PCB minimum order covers five boards).

## Alternative without a custom PCB

The base is designed around the custom Ø110 board (the USB-C, switch and LED openings, the mounting
bosses and the centre wire slot are placed for it). A module-based build (ESP32 dev board + TP4056 module
+ MT3608 module + TTP223 touch module + 2 wire-lead 18650 holders) is electrically equivalent but does not
fit the Ø113 x 23 mm cavity as-is: you would raise `base_height` in `cad/tablelight.py` by ~15 mm and print a
custom tray. The wiring is the same as the block diagram: TP4056 OUT -> MT3608 IN -> 5 V, TP4056 OUT -> dev
board 5V/VIN pin (its LDO), GPIO2 data through a 330 R, TTP223 OUT to a GPIO configured as a WLED button.

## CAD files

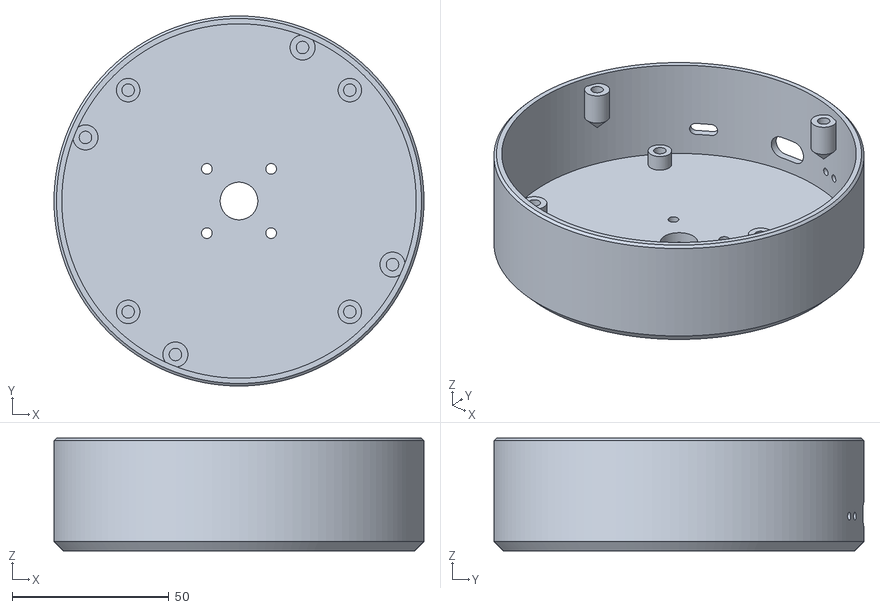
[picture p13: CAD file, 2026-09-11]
cad/stl/base_shell.stl
118.0 x 118.0 x 36.0

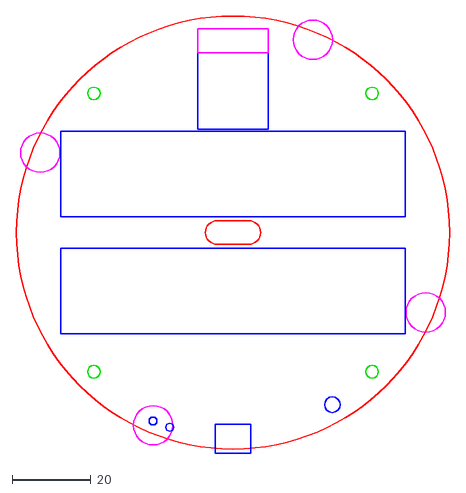
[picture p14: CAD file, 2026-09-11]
hardware/pcb/outline.dxf
110.0 x 111.0

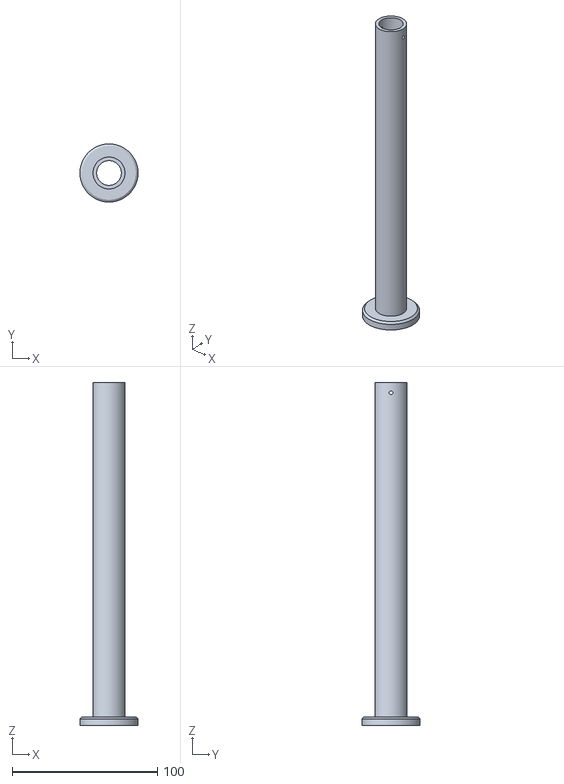
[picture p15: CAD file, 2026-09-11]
cad/stl/stem.stl
40.0 x 40.0 x 236.0

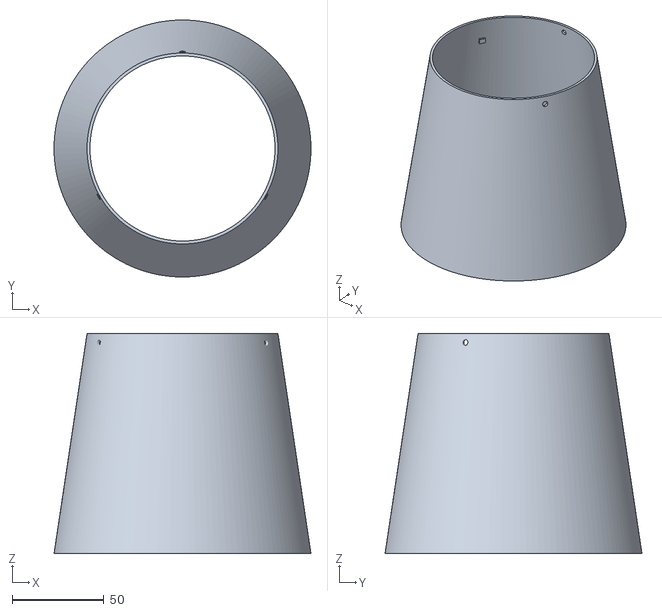
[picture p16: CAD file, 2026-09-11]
cad/stl/cone_shade.stl
140.0 x 140.0 x 120.0

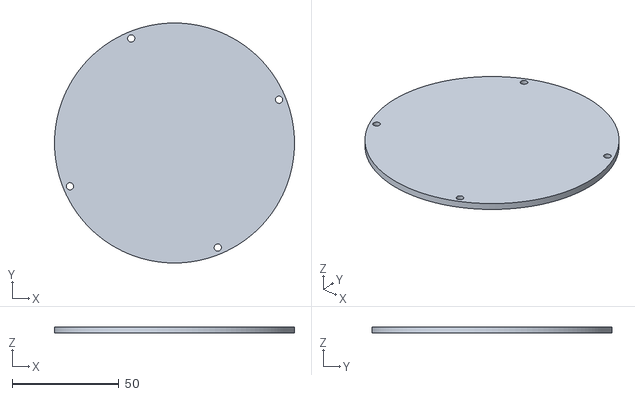
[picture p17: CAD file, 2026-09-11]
cad/stl/base_bottom_plate.stl
112.4 x 112.4 x 3.00

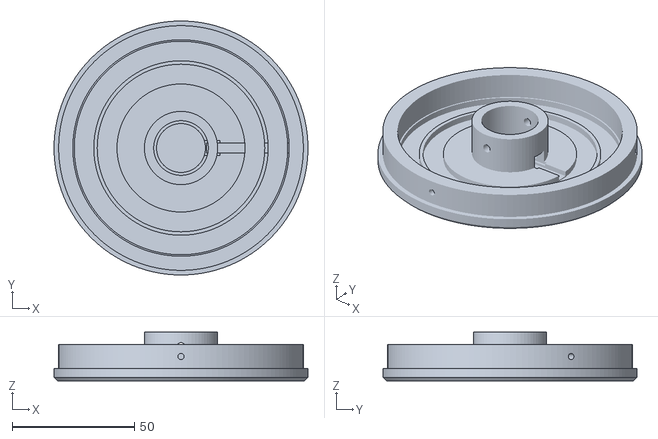
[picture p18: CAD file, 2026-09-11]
cad/stl/head_plate.stl
104.0 x 104.0 x 20.0

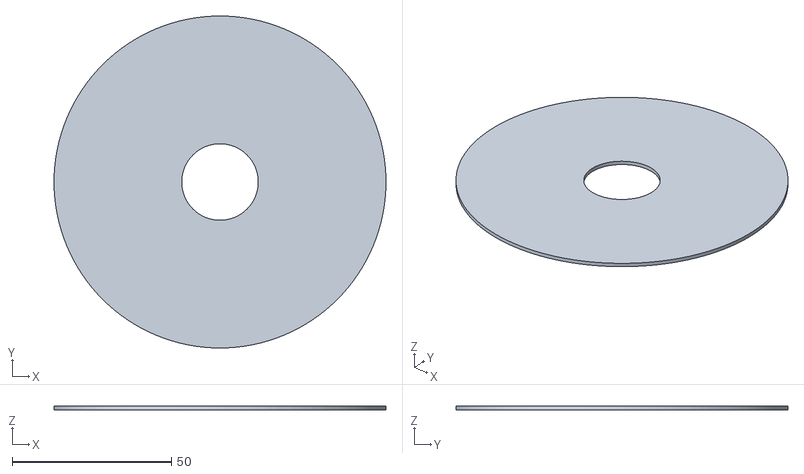
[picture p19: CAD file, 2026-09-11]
cad/stl/head_diffuser.stl
104.2 x 104.2 x 1.20

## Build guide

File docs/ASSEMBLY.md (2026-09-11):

# TableLight - assembly

Coordinate reference: the CAD origin is the centre of the base deck (top face of the base disc). "Down" is
toward the bottom plate. The PCB hangs under the deck with its components facing DOWN, so everything
electrical is reachable by removing the bottom plate. The wires from the head run down the stem, through
the Ø12 deck hole and the 14 x 6 slot in the PCB centre to the connectors on the component side.

## 0. Before you start

* PCB assembled and bench-tested (`hardware/pcb/README.md`, "bring-up").
* WLED flashed and configured (`docs/WLED_SETUP.md`) - easier before the board is inside the base.
* Heat-set inserts fitted (`docs/PRINTING.md`): 4 deck bosses, 4 stem flange, 4 shell bosses.

## 1. Head: LED ring(s) and touch pad

1. Solder three 300 mm silicone leads (5V, GND, DIN) to the 24-LED ring's input pads. If you use the optional
   16-LED inner ring, first wire 24-ring DOUT / 5V / GND to the 16-ring DIN / 5V / GND with 40 mm jumpers.
2. Turn the head plate upside down. The two circular channels are 2.5 mm deep. Put 1 mm double-sided foam
   tape on the back of the ring(s), lay the input pads over the **radial wire groove** (the 4 mm slot running
   from the outer channel to the central socket) and press the ring(s) in, LEDs facing out (down when fitted).
3. Route the three leads along the groove, through the **notch in the socket wall**, and let them hang out of
   the socket bore.
4. Cut a **Ø18 copper foil disc**, solder a 300 mm wire to it first, then stick it into the **Ø20 recess at the
   top of the socket bore**. Cover with Kapton. That wire also goes down the bore.
5. Bench test the ring(s) from the PCB before going further.

## 2. Head: shade and diffuser

1. Push the diffuser disc into the cone from the wide end, up past the three nubs (it flexes) until it rests
   on them, 14 mm below the top edge. Its Ø24 centre hole is for the stem.
2. Drop the head plate onto the cone: the skirt enters the cone top, the Ø104 lip sits flush on the rim.
   Rotate until the three Ø3.4 holes in the cone line up with the three Ø2.6 holes in the skirt and drive
   **3 x M3 x 6 black button-head screws** (they self-tap into the skirt).

## 3. Stem

1. Feed the four wires (5V, GND, DIN, TOUCH) from the head through the stem, flange end last.
2. Push the stem into the head socket until it bottoms (13 mm in). Its two Ø2.6 holes align with the two
   Ø3.4 holes in the socket boss; drive **2 x M3 x 6** through the boss into the stem.
3. Crimp / solder the **3-pin JST-PH** (5V, GND, DIN) and the **2-pin JST-PH** (TOUCH, blank) on the wire ends.

## 4. Base

1. Stand the stem on the deck, flange centred over the Ø12 hole, wires hanging through. From underneath drive
   **4 x M3 x 8** through the deck holes into the flange inserts.
2. Hold the PCB under the deck, components facing down, **USB-C toward the −Y wall opening**. Pass the two
   plugs through the 14 x 6 slot and plug them into J2 (LED) and J3 (touch).
3. Slide the board up so the USB-C receptacle enters its slot and the slide switch actuator enters its slot;
   fit **4 x M3 x 6** through the PCB holes into the deck bosses. Check the USB-C opening is central on the
   receptacle and the two charge LEDs sit behind their Ø2.5 holes.
4. Insert **1 or 2 x 18650** (same model, same charge state), positive toward the "+" marked ends of the
   holders (both holders are in parallel).
5. Screw the **bottom plate** on with **4 x M3 x 8** into the shell bosses; stick the **4 rubber feet** into
   their recesses.

## 5. First light

Slide switch ON. Plug in USB-C: red LED = charging, green = full. Touch the white top: WLED toggles. The
light falls through the diffuser onto the table; the cone stays dark outside.

## Wiring summary

| From | To | Wire |
|---|---|---|
| J2.1 VLED | 24-ring 5V | red, 300 mm |
| J2.2 GND | 24-ring GND | black, 300 mm |
| J2.3 DATA | 24-ring DIN | any, 300 mm |
| 24-ring DOUT / 5V / GND | 16-ring DIN / 5V / GND (optional) | 3 x 40 mm inside the head |
| J3.1 TOUCH_PAD | copper disc in the socket recess | 1 wire, 300 mm (twist it with the GND wire) |

## Servicing

Four bottom-plate screws: batteries, connectors, RESET/BOOT buttons and the expansion header are all on the
exposed component side. Two socket screws release the whole head from the stem; three cone screws release the
shade from the head plate.

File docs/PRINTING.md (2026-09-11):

# TableLight - printing guide

All STLs in `cad/stl/` are exported in their print orientation with Z = build direction and the part
resting on Z = 0. No supports are needed for any part.

| Part | Orientation (as exported) | Layer | Walls | Infill | Notes |
|---|---|---|---|---|---|
| `base_shell.stl` | upside down: honeycomb deck on the bed, walls up | 0.2 mm | 3 (1.2 mm) | 15 % | The deck face is the visible top of the base; the 1.5 mm hexagon pockets print as walls rising from the bed and come out crisp on a smooth sheet. The four bottom-plate bosses have 45 deg cones so they need no support. The USB-C / switch slots are short horizontal bridges (13 mm max). |
| `base_bottom_plate.stl` | flat, outer face down | 0.2 mm | 3 | 20 % | Screw-head and foot recesses face the bed. |
| `stem.stl` | upright, flange on the bed | 0.2 mm | 3 | any (it is a tube) | 236 mm tall, Ø22: slow the outer wall to ~40 mm/s above 150 mm, enable Z-hop, use a brim if adhesion is marginal. The two Ø2.6 screw holes near the top are self-tapped by the M3 head screws. Needs 240 mm of Z travel - reduce `stem_len` in `cad/tablelight.py` if you have less. |
| `head_plate.stl` | upside down: white top face on the bed, skirt and socket pointing up | 0.2 mm | 3 | 20 % | White PLA. The ring channels and the touch recess face up and need no support. 20 mm tall as printed. |
| `cone_shade.stl` | upright, wide end on the bed | 0.2 mm (0.16 for a smoother surface) | 3 perimeters, **0 top layers, 0 infill** | - | Plain 1.6 mm wall cone leaning 8.5 deg inward - also fine in **vase mode** with a 0.8 mm line (then the 3 screw holes are lost: drill them, or glue the cone to the skirt). Three 1.5 mm nubs inside near the top hold the diffuser; they are tiny overhangs and print fine. Print black for the look in the reference render, or white/light grey for 20-30 % more light on the table. |
| `head_diffuser.stl` | flat | 0.2 mm | 3 | 100 % (it is 1.2 mm) | Natural/white translucent PLA or PETG. It flexes past the nubs on the way in. |

## Materials

* Base, plate, stem, cone: PLA is fine (nothing in the base gets hot: worst case ~2 W in the charger for a
  few minutes, ~1 W in the boost at full brightness). Dark colours hide the electronics through the switch slot.
* Head plate: white, opaque. It is the visible top; a matte white looks closest to the render.
* Diffuser: translucent. The LEDs sit 12 mm above it, so hotspots are soft; 4 perimeters or 0.16 mm layers
  if you want it even smoother.

## Tolerances built into the model

| Interface | Nominal clearance |
|---|---|
| Head skirt inside the cone top | 0.3 mm radial |
| Stem in the head socket | 0.2 mm radial (friction fit + 2 screws) |
| Diffuser disc in the cone | 0.4 mm radial at the nub height |
| PCB (Ø110) in the base cavity (Ø113) | 1.5 mm radial |
| Bottom plate in the shell | 0.3 mm radial |
| Heat-set insert holes | Ø4.0 mm, 6 mm deep |
| Screw clearance holes | Ø3.4 mm |

If your printer runs tight, scale nothing - edit `skirt_clear`, `socket_clear`, `diffuser_clear` or
`plate_clear` in `cad/tablelight.py` and regenerate.

## Heat-set inserts (12 x M3)

* 4 in the deck bosses inside the base shell (for the PCB screws) - insert from below.
* 4 in the stem flange - insert from below (the flange is 6 mm thick: use 4-5 mm long inserts here).
* 4 in the shell's bottom bosses (for the bottom plate) - insert from below.

Push straight; the bosses are 7.5-8 mm in diameter so a bit of melt bulge is fine. Let them cool before
loading. The five black M3 x 6 screws for the cone and the head socket are self-tapping into Ø2.6 holes - no
inserts.

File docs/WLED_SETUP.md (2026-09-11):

# TableLight - WLED setup

## Firmware

Two options:

1. **Stock WLED (ESP32 build) from the web installer** - everything works (LEDs, touch button, relay pin)
   except the battery percentage.
2. **Custom build with the Battery usermod** - copy `firmware/wled/platformio_override.ini` into a WLED
   source checkout and build the `tablelight` environment (`pio run -e tablelight`). This adds the battery
   readout to the UI and MQTT/Home Assistant and bakes in the pin defaults below.

Flashing: plug the lamp's USB-C into the computer (data cable!). The CH340C shows up as a serial port; the
auto-reset circuit means esptool / the web installer need no button presses. If a board ever refuses: hold
BOOT (SW3), tap RESET (SW2), release BOOT, flash.

## Settings -> LED preferences

| Setting | Value | Why |
|---|---|---|
| LED type | SK6812 RGBW (or WS2812B if that is what your ring is) | |
| Colour order | GRB (check with a red-only test) | |
| Length | **24** (40 with the optional inner ring) | |
| GPIO | **2** | LED_DATA, level shifted to 5 V on the board |
| Enable automatic brightness limiter | on, **1200 mA** | boost converter and protection headroom |
| LED voltage / mA per LED | 5 V, 55 mA | for the limiter |
| Relay GPIO | **16**, active high, *not* inverted | LED_EN: powers the 5 V LED rail only while the light is on |
| Auto-off / turn LEDs off after | as you like | with the relay pin the ring draws nothing when off |

With two rings, make segment 0 = LEDs 0-23 (outer) and segment 1 = LEDs 24-39 (inner) so you can run a
warm white outer ring with a coloured accent in the middle, or map them as a 2-ring "2D" via segment groups.

## Settings -> LED preferences -> Buttons

| Button | GPIO | Type |
|---|---|---|
| Button 0 | **4** | **Touch (capacitive)** |
| Touch threshold | start at 32 (default); lower = more sensitive | 2 mm of PLA over a Ø18 pad usually needs 20-30 |

Touch actions are the WLED defaults: short press = toggle, long press = brightness ramp, double = preset.
Tune the threshold until a fingertip on the white top toggles reliably but a hand near the lamp does not.
Typical raw values through 2 mm plastic with this pad: ~60-70 untouched, ~20-30 touched.

## Battery usermod (custom build only)

| Setting | Value |
|---|---|
| Battery type | Li-ion |
| Measurement pin | **35** |
| Voltage multiplier / calibration | 2.0 (100k/100k divider) - then trim so the reading matches a multimeter on the cell |
| Min / max voltage | 3.0 V / 4.2 V |
| Read interval | 30 s |
| Auto-off when low | 5 % (recommended - the DW01 cuts at 2.4 V, lower than you want for cell life) |

## Other pins on the board

| GPIO | Function |
|---|---|
| 34 | VBUS present (1 = USB plugged in). Usable for a "charging" preset via a small usermod; unused by stock WLED |
| 25, 26, 32, 33 | free on the expansion header J4 (IR receiver on 25 is a common addition) |
| 0, 1, 3, EN | BOOT / UART / RESET - do not reassign |

## Recommended presets

* "Lamp": solid warm white via the W channel, 70 % -> about 0.8 A, 5 h on two 3500 mAh cells.
* "Cosy": Candle Multi, 30 % -> ~12 h.
* "Night": solid 2200 K, 8 %, auto-off 30 min.

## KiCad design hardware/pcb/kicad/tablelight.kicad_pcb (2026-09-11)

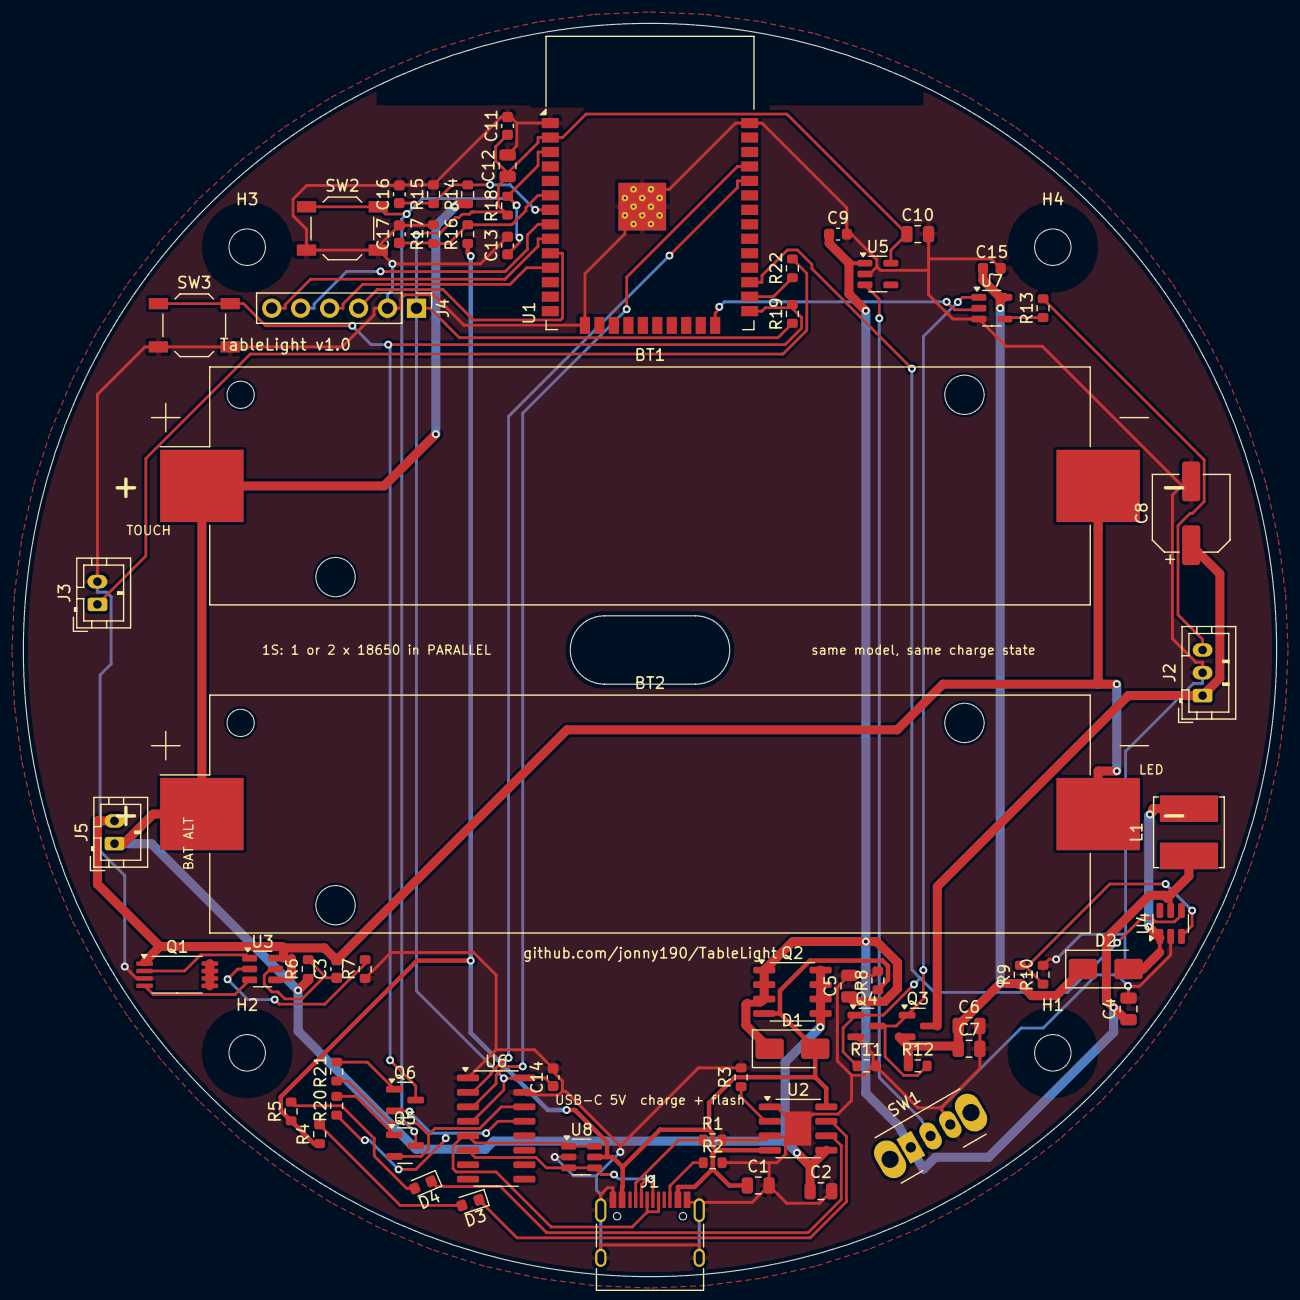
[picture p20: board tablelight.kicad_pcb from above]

Board: 2 copper layers, 110.0 x 110.0 mm, 72 parts (0 on the bottom side), 46 nets.

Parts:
BT1: 18650; BatteryHolder_Keystone_1042_1x18650
BT2: 18650 (optional 2nd cell); BatteryHolder_Keystone_1042_1x18650
C1, C2, C10, C12: 10uF 10V; C_0805_2012Metric
C3, C11, C14, C15, C16, C17: 100nF; C_0603_1608Metric
C4, C5, C6, C7: 22uF 10V; C_0805_2012Metric
C8: 100uF 6.3V; CP_Elec_6.3x5.4
C9, C13: 1uF; C_0603_1608Metric
D1, D2: SS34; D_SMA
D3: RED; LED_0603_1608Metric
D4: GREEN; LED_0603_1608Metric
H1, H2, H3, H4: M3; MountingHole_3.2mm_M3
J1: USB-C 16P; USB_C_Receptacle_HRO_TYPE-C-31-M-12
J2: LED RING; JST_PH_B3B-PH-K_1x03_P2.00mm_Vertical
J3: TOUCH; JST_PH_B2B-PH-K_1x02_P2.00mm_Vertical
J4: EXP; PinHeader_1x06_P2.54mm_Vertical
J5: BAT ALT; JST_PH_B2B-PH-K_1x02_P2.00mm_Vertical
L1: 4.7uH 4A; L_Bourns_SRN6045TA
Q1: FS8205A; TSSOP-8_4.4x3mm_P0.65mm
Q2: AO4407A; SOIC-8_3.9x4.9mm_P1.27mm
Q3: AO3401A; SOT-23
Q4: 2N7002; SOT-23
Q5, Q6: MMBT3904; SOT-23
R1, R2: 5.1k; R_0603_1608Metric
R3: 1.2k; R_0603_1608Metric
R4, R5, R7, R22: 1k; R_0603_1608Metric
R6: 100R; R_0603_1608Metric
R8, R11, R14, R15, R16, R17: 100k; R_0603_1608Metric
R9: 75k; R_0603_1608Metric
R10, R12, R18, R19: 10k; R_0603_1608Metric
R13: 330R; R_0603_1608Metric
R20, R21: 12k; R_0603_1608Metric
SW1: POWER; SW_Slide_SPDT_Angled_CK_OS102011MA1Q
SW2: RESET; SW_SPST_TL3342
SW3: BOOT; SW_SPST_TL3342
U1: ESP32-WROOM-32E-N4; ESP32-WROOM-32
U2: TP4056; SOIC-8-1EP_3.9x4.9mm_P1.27mm_EP2.29x3mm
U3: DW01A; SOT-23-6
U4: MT3608; SOT-23-6
U5: AP2112K-3.3; SOT-23-5
U6: CH340C; SOIC-16_3.9x9.9mm_P1.27mm
U7: 74AHCT1G125; SOT-23-5
U8: USBLC6-2SC6; SOT-23-6

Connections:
3V3: C10.1, C11.1, C12.1, C14.1, J4.1, R18.1, R19.1, U1.2, U5.5, U6.4, U6.16
+5V: C6.1, C7.1, C15.1, D2.1, Q3.2, R9.1, R12.1, U7.5
BAT+: BT1.1, BT2.1, C2.1, J5.1, Q2.5, Q2.6, Q2.7, Q2.8, R6.1, R14.1, U2.5
BOOST_FB: R9.2, R10.1, U4.3
BOOST_SW: D2.2, L1.2, U4.1
CC1: J1.A5, R1.1
CC2: J1.B5, R2.1
CELL-: BT1.2, BT2.2, C3.2, J5.2, Q1.1, U3.4, U3.6
CHRG: D3.1, U2.7
DTR: Q6.2, R20.1, U6.13
DTR_B: Q5.1, R20.2
DW01_CS: R7.2, U3.2
DW01_OC: Q1.4, U3.3
DW01_OD: Q1.2, U3.1
DW01_VCC: C3.1, R6.2, U3.5
EN: C13.1, Q5.3, R18.2, SW2.1, U1.3
GND: C1.2, C2.2, C4.2, C5.2, C6.2, C7.2, C8.2, C9.2, C10.2, C11.2, C12.2, C13.2, C14.2, C15.2, C16.2, C17.2, J1.A1, J1.A12, J1.B1, J1.B12, J1.S1, J2.2, J3.2, J4.2, Q1.3, Q4.2, R1.2, R2.2, R3.2, R7.1, R8.2, R10.2, R11.2, R15.2, R17.2, SW1.3, SW2.2, SW3.2, U1.1, U1.15, U1.38, U1.39, U2.1, U2.3, U2.9, U4.2, U5.2, U6.1, U6.15, U7.3, U8.2
IO0: Q6.3, R19.2, SW3.1, U1.25
IO25: J4.3, U1.10
IO26: J4.4, U1.11
IO32: J4.5, U1.8
IO33: J4.6, U1.9
LED_DATA: U1.24, U7.2
LED_DATA_5V: R13.1, U7.4
LED_DOUT: J2.3, R13.2
LED_EN: Q4.1, R11.1, U1.27, U4.4
unnamed: R3.1, U2.2
unnamed: D3.2, R4.2
unnamed: D4.2, R5.2
PROT_FET_D: Q1.5, Q1.6, Q1.7, Q1.8
RTS: Q5.2, R21.1, U6.14
RTS_B: Q6.1, R21.2
STDBY: D4.1, U2.6
SYS_EN: SW1.2, U5.3
TOUCH: R22.1, U1.26
TOUCH_PAD: J3.1, R22.2
U0RXD: U1.34, U6.2
U0TXD: U1.35, U6.3
USB_D+: J1.A6, J1.B6, U6.5, U8.1, U8.6
USB_D-: J1.A7, J1.B7, U6.6, U8.3, U8.4
VBAT_SENSE: C16.1, R14.2, R15.1, U1.7
VBUS: C1.1, D1.2, J1.A4, J1.A9, J1.B4, J1.B9, Q2.4, R4.1, R5.1, R8.1, R16.1, U2.4, U2.8, U8.5
VBUS_DET: C17.1, R16.2, R17.1, U1.6
VLED: C8.1, J2.1, Q3.3
VSYS: C4.1, C5.1, C9.1, D1.1, L1.1, Q2.1, Q2.2, Q2.3, SW1.1, U4.5, U5.1
nLED_EN: Q3.1, Q4.3, R12.2, U7.1

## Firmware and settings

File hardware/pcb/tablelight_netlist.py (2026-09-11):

#!/usr/bin/env python3
"""
TableLight controller PCB - circuit definition (single source of truth).

Written with SKiDL so the same Python object graph produces:
  * tablelight.net      KiCad netlist -> pcbnew: File > Import Netlist (footprints pre-assigned)
  * bom_pcb.csv         PCB bill of materials
  * SCHEMATIC.md        human readable schematic: every net and every pin it touches

    pip install skidl        (plus: rich simp_sexp ply)
    python3 hardware/pcb/tablelight_netlist.py

Design summary
--------------
1S Li-ion (1 or 2 x 18650 in PARALLEL) -> protected pack (DW01A + FS8205A)
USB-C 5 V in (5.1k CC pull-downs, works with C-C cables) -> TP4056 1 A charger
Load sharing: Schottky from VBUS to VSYS, P-FET (AO4407A) from pack to VSYS
   -> LEDs/ESP run from USB while charging; the charger sees only the cell.
VSYS -> MT3608 boost -> +5V (LED rail for the 24 (+16) LED rings, WLED current limit 1.2 A)
        -> AO3401A high-side switch -> VLED  (WLED "relay pin" GPIO16, true off)
VSYS -> AP2112K-3.3 LDO (EN = slide switch) -> 3V3 for the ESP32-WROOM-32E
USB data -> CH340C (3.3 V mode) -> UART0 with DTR/RTS auto-reset -> flash WLED over the same USB-C
74AHCT1G125 level shifter 3.3 -> 5 V for the LED data line (OE tied to the LED power switch)
ESP32 native capacitive touch on GPIO4 (T0) -> copper pad under the white head plate
Battery voltage divider -> GPIO35 for the WLED Battery usermod; VBUS detect -> GPIO34
"""
import csv
import logging
import os
from collections import defaultdict

from skidl import (ERC, SKIDL, TEMPLATE, KICAD8, Net, Part, Pin, generate_netlist, set_default_tool)

set_default_tool(KICAD8)
HERE = os.path.dirname(os.path.abspath(__file__))


class _DropTagNoise(logging.Filter):
    """SKiDL warns about auto-generated hierarchy tags for every part; irrelevant for a flat netlist."""
    def filter(self, record):
        msg = record.getMessage()
        return not ("tag" in msg and ("Random tag" in msg or "Missing tag" in msg))


for _name in ("skidl", "skidl.erc"):
    logging.getLogger(_name).addFilter(_DropTagNoise())

T = Pin.types
PAS, IN, OUT, PWR, PWO, BI, OC, NC = T.PASSIVE, T.INPUT, T.OUTPUT, T.PWRIN, T.PWROUT, T.BIDIR, T.OPENCOLL, T.NOCONNECT


def tmpl(name, prefix, footprint, pins, **fields):
    """Create a part template with explicit pins (num, name, type)."""
    p = Part(tool=SKIDL, name=name, ref_prefix=prefix, dest=TEMPLATE, footprint=footprint, **fields)
    for num, pname, ptype in pins:
        p += Pin(num=str(num), name=pname, func=ptype)
    return p


# ----------------------------------------------------------------------------
# part templates (footprint names are from the standard KiCad 8 libraries)
# ----------------------------------------------------------------------------
R = tmpl("R", "R", "Resistor_SMD:R_0603_1608Metric", [(1, "1", PAS), (2, "2", PAS)], description="Resistor 0603 1%")
C = tmpl("C", "C", "Capacitor_SMD:C_0603_1608Metric", [(1, "1", PAS), (2, "2", PAS)], description="Capacitor 0603 X7R")
C0805 = tmpl("C", "C", "Capacitor_SMD:C_0805_2012Metric", [(1, "1", PAS), (2, "2", PAS)], description="Capacitor 0805 X5R")
CP = tmpl("C_Polarized", "C", "Capacitor_SMD:CP_Elec_6.3x5.4", [(1, "+", PAS), (2, "-", PAS)], description="Electrolytic / polymer cap SMD 6.3x5.4")
D_SMA = tmpl("D_Schottky", "D", "Diode_SMD:D_SMA", [(1, "K", PAS), (2, "A", PAS)], description="Schottky diode SMA")
LED = tmpl("LED", "D", "LED_SMD:LED_0603_1608Metric", [(1, "K", PAS), (2, "A", PAS)], description="LED 0603")
L = tmpl("L", "L", "Inductor_SMD:L_Bourns_SRN6045TA", [(1, "1", PAS), (2, "2", PAS)], description="Power inductor 6x6 mm shielded")

ESP32 = tmpl("ESP32-WROOM-32E", "U", "RF_Module:ESP32-WROOM-32", [
    (1, "GND", PWR), (2, "3V3", PWR), (3, "EN", IN), (4, "SENSOR_VP", IN), (5, "SENSOR_VN", IN),
    (6, "IO34", IN), (7, "IO35", IN), (8, "IO32", BI), (9, "IO33", BI), (10, "IO25", BI),
    (11, "IO26", BI), (12, "IO27", BI), (13, "IO14", BI), (14, "IO12", BI), (15, "GND", PWR),
    (16, "IO13", BI), (17, "NC", NC), (18, "NC", NC), (19, "NC", NC), (20, "NC", NC),
    (21, "NC", NC), (22, "NC", NC), (23, "IO15", BI), (24, "IO2", BI), (25, "IO0", BI),
    (26, "IO4", BI), (27, "IO16", BI), (28, "IO17", BI), (29, "IO5", BI), (30, "IO18", BI),
    (31, "IO19", BI), (32, "NC", NC), (33, "IO21", BI), (34, "RXD0", BI), (35, "TXD0", BI),
    (36, "IO22", BI), (37, "IO23", BI), (38, "GND", PWR), (39, "GND", PWR)],
    description="ESP32-WROOM-32E-N4 WiFi/BT module, 4 MB flash", mpn="ESP32-WROOM-32E-N4")

TP4056 = tmpl("TP4056", "U", "Package_SO:SOIC-8-1EP_3.9x4.9mm_P1.27mm_EP2.29x3mm", [
    (1, "TEMP", IN), (2, "PROG", PAS), (3, "GND", PWR), (4, "VCC", PWR), (5, "BAT", PWO),
    (6, "STDBY", OC), (7, "CHRG", OC), (8, "CE", IN), (9, "EP", PWR)],
    description="1 A linear Li-ion charger, ESOP-8", mpn="TP4056")

DW01 = tmpl("DW01A", "U", "Package_TO_SOT_SMD:SOT-23-6", [
    (1, "OD", OUT), (2, "CS", IN), (3, "OC", OUT), (4, "TD", IN), (5, "VCC", PWR), (6, "GND", PWR)],
    description="1S Li-ion protection IC", mpn="DW01A-G")

FS8205 = tmpl("FS8205A", "Q", "Package_SO:TSSOP-8_4.4x3mm_P0.65mm", [
    (1, "S1", PAS), (2, "G1", IN), (3, "S2", PAS), (4, "G2", IN), (5, "D2", PAS), (6, "D2", PAS), (7, "D1", PAS), (8, "D1", PAS)],
    description="Dual N-MOSFET common drain, 20 V, 6 A (battery protection)", mpn="FS8205A")

MT3608 = tmpl("MT3608", "U", "Package_TO_SOT_SMD:SOT-23-6", [
    (1, "SW", PAS), (2, "GND", PWR), (3, "FB", IN), (4, "EN", IN), (5, "IN", PWR), (6, "NC", NC)],
    description="Boost converter 2-24 V in, 1.2 MHz, 4 A switch", mpn="MT3608")

AP2112 = tmpl("AP2112K-3.3", "U", "Package_TO_SOT_SMD:SOT-23-5", [
    (1, "VIN", PWR), (2, "GND", PWR), (3, "EN", IN), (4, "NC", NC), (5, "VOUT", PWO)],
    description="LDO 3.3 V 600 mA low dropout", mpn="AP2112K-3.3TRG1")

CH340 = tmpl("CH340C", "U", "Package_SO:SOIC-16_3.9x9.9mm_P1.27mm", [
    (1, "GND", PWR), (2, "TXD", OUT), (3, "RXD", IN), (4, "V3", PWR), (5, "UD+", BI), (6, "UD-", BI),
    (7, "XI", NC), (8, "XO", NC), (9, "CTS#", IN), (10, "DSR#", IN), (11, "RI#", IN), (12, "DCD#", IN),
    (13, "DTR#", OUT), (14, "RTS#", OUT), (15, "R232", IN), (16, "VCC", PWR)],
    description="USB-UART bridge, internal oscillator", mpn="CH340C")

AHCT125 = tmpl("74AHCT1G125", "U", "Package_TO_SOT_SMD:SOT-23-5", [
    (1, "OE#", IN), (2, "A", IN), (3, "GND", PWR), (4, "Y", OUT), (5, "VCC", PWR)],
    description="Single bus buffer, 3.3->5 V level shift for LED data", mpn="SN74AHCT1G125DBVR")

USBLC6 = tmpl("USBLC6-2SC6", "U", "Package_TO_SOT_SMD:SOT-23-6", [
    (1, "IO1", PAS), (2, "GND", PWR), (3, "IO2", PAS), (4, "IO2", PAS), (5, "VBUS", PWR), (6, "IO1", PAS)],
    description="USB ESD protection (optional)", mpn="USBLC6-2SC6")

PFET8 = tmpl("Q_PMOS_SOIC8", "Q", "Package_SO:SOIC-8_3.9x4.9mm_P1.27mm", [
    (1, "S", PAS), (2, "S", PAS), (3, "S", PAS), (4, "G", IN), (5, "D", PAS), (6, "D", PAS), (7, "D", PAS), (8, "D", PAS)],
    description="P-MOSFET -30 V 12 A 12 mOhm (load sharing)", mpn="AO4407A")
PFET = tmpl("Q_PMOS_SOT23", "Q", "Package_TO_SOT_SMD:SOT-23", [(1, "G", IN), (2, "S", PAS), (3, "D", PAS)],
            description="P-MOSFET -30 V 4 A (LED rail switch)", mpn="AO3401A")
NFET = tmpl("Q_NMOS_SOT23", "Q", "Package_TO_SOT_SMD:SOT-23", [(1, "G", IN), (2, "S", PAS), (3, "D", PAS)],
            description="N-MOSFET 60 V 300 mA", mpn="2N7002")
NPN = tmpl("Q_NPN_SOT23", "Q", "Package_TO_SOT_SMD:SOT-23", [(1, "B", IN), (2, "E", PAS), (3, "C", PAS)],
           description="NPN transistor (auto-reset)", mpn="MMBT3904")

USBC = tmpl("USB_C_Receptacle_16P", "J", "Connector_USB:USB_C_Receptacle_HRO_TYPE-C-31-M-12", [
    ("A1", "GND", PWR), ("A4", "VBUS", PWR), ("A5", "CC1", BI), ("A6", "D+", BI), ("A7", "D-", BI), ("A8", "SBU1", NC),
    ("A9", "VBUS", PWR), ("A12", "GND", PWR), ("B1", "GND", PWR), ("B4", "VBUS", PWR), ("B5", "CC2", BI),
    ("B6", "D+", BI), ("B7", "D-", BI), ("B8", "SBU2", NC), ("B9", "VBUS", PWR), ("B12", "GND", PWR), ("S1", "SHIELD", PAS)],
    description="USB-C receptacle 16 pin, top mount", mpn="HRO TYPE-C-31-M-12")
JST3 = tmpl("Conn_JST_PH_3", "J", "Connector_JST:JST_PH_B3B-PH-K_1x03_P2.00mm_Vertical", [(1, "1", PAS), (2, "2", PAS), (3, "3", PAS)],
            description="JST PH 2.0 mm 3 pin", mpn="B3B-PH-K-S")
JST2 = tmpl("Conn_JST_PH_2", "J", "Connector_JST:JST_PH_B2B-PH-K_1x02_P2.00mm_Vertical", [(1, "1", PAS), (2, "2", PAS)],
            description="JST PH 2.0 mm 2 pin", mpn="B2B-PH-K-S")
HDR6 = tmpl("Conn_01x06", "J", "Connector_PinHeader_2.54mm:PinHeader_1x06_P2.54mm_Vertical",
            [(i, str(i), PAS) for i in range(1, 7)], description="Pin header 1x6 2.54 mm (expansion)", mpn="generic")
BATT = tmpl("BatteryHolder_18650", "BT", "Battery:BatteryHolder_Keystone_1042_1x18650", [(1, "+", PAS), (2, "-", PAS)],
            description="18650 PCB-mount holder", mpn="Keystone 1042 (or BH-18650-PC equiv.)")
SW_SLIDE = tmpl("SW_SPDT_Slide", "SW", "Button_Switch_THT:SW_Slide_SPDT_Angled_CK_OS102011MA1Q", [(1, "1", PAS), (2, "COM", PAS), (3, "3", PAS)],
                description="Slide switch SPDT right-angle THT (power)", mpn="C&K OS102011MA1QN1")
SW_TACT = tmpl("SW_Push", "SW", "Button_Switch_SMD:SW_SPST_TL3342", [(1, "1", PAS), (2, "2", PAS)],
               description="Tactile switch 3x6x2.5 mm SMD", mpn="TL3342 / TS-1187A")
MH = tmpl("MountingHole", "H", "MountingHole:MountingHole_3.2mm_M3", [], description="M3 mounting hole (r=45 mm, 45/135/225/315 deg)", mpn="-")

# ----------------------------------------------------------------------------
# nets
# ----------------------------------------------------------------------------
GND = Net("GND")
VBUS = Net("VBUS")
BATP = Net("BAT+")           # cell(s) positive == protected pack positive
CELLN = Net("CELL-")         # raw cell negative (before protection FETs)
FETD = Net("PROT_FET_D")     # common drain node of FS8205A
VSYS = Net("VSYS")           # load-shared rail: VBUS-0.4 V when USB present, else pack
V5 = Net("+5V")              # boost output
VLED = Net("VLED")           # switched LED rail
V3 = Net("3V3")
CC1, CC2 = Net("CC1"), Net("CC2")
DP, DM = Net("USB_D+"), Net("USB_D-")
CHRG, STDBY = Net("CHRG"), Net("STDBY")
DW_VCC, DW_CS = Net("DW01_VCC"), Net("DW01_CS")
OD, OC_ = Net("DW01_OD"), Net("DW01_OC")
SWN, FB = Net("BOOST_SW"), Net("BOOST_FB")
LED_EN = Net("LED_EN")       # GPIO16 (WLED relay pin, active high)
nLED_EN = Net("nLED_EN")     # gate of the LED P-FET / OE# of level shifter
LED_DATA = Net("LED_DATA")   # GPIO2, 3.3 V
LED_DATA5 = Net("LED_DATA_5V")
LED_OUT = Net("LED_DOUT")
TOUCH = Net("TOUCH")         # GPIO4 / T0
TOUCH_PAD = Net("TOUCH_PAD")
VBAT_S, VBUS_D = Net("VBAT_SENSE"), Net("VBUS_DET")
EN, IO0 = Net("EN"), Net("IO0")
TX, RX = Net("U0TXD"), Net("U0RXD")   # named from the ESP32 side
DTR, RTS = Net("DTR"), Net("RTS")
DTR_B, RTS_B = Net("DTR_B"), Net("RTS_B")
SYS_EN = Net("SYS_EN")
IO25, IO26, IO32, IO33 = Net("IO25"), Net("IO26"), Net("IO32"), Net("IO33")

# ----------------------------------------------------------------------------
# USB-C input, ESD, charger, status LEDs
# ----------------------------------------------------------------------------
J1 = USBC(ref="J1", value="USB-C 16P")
GND += J1["A1"], J1["A12"], J1["B1"], J1["B12"], J1["S1"]
VBUS += J1["A4"], J1["A9"], J1["B4"], J1["B9"]
CC1 += J1["A5"]; CC2 += J1["B5"]
DP += J1["A6"], J1["B6"]; DM += J1["A7"], J1["B7"]
R1 = R(ref="R1", value="5.1k", remark="CC1 Rd -> sink advertises 5 V device"); CC1 += R1[1]; GND += R1[2]
R2 = R(ref="R2", value="5.1k", remark="CC2 Rd"); CC2 += R2[1]; GND += R2[2]
U8 = USBLC6(ref="U8", value="USBLC6-2SC6", remark="optional ESD protection")
DP += U8[1], U8[6]; DM += U8[3], U8[4]; VBUS += U8[5]; GND += U8[2]

U2 = TP4056(ref="U2", value="TP4056")
VBUS += U2["VCC"], U2["CE"]
GND += U2["GND"], U2["EP"], U2["TEMP"]
BATP += U2["BAT"]
R3 = R(ref="R3", value="1.2k", remark="PROG: 1.2k = 1.0 A charge; use 2k for 0.58 A (weak USB ports)"); U2["PROG"] += R3[1]; GND += R3[2]
C1 = C0805(ref="C1", value="10uF 10V"); VBUS += C1[1]; GND += C1[2]
C2 = C0805(ref="C2", value="10uF 10V"); BATP += C2[1]; GND += C2[2]
D3 = LED(ref="D3", value="RED", remark="CHRG: on while charging"); CHRG += D3["K"]
D4 = LED(ref="D4", value="GREEN", remark="STDBY: on when charge complete"); STDBY += D4["K"]
R4 = R(ref="R4", value="1k"); VBUS += R4[1]; D3["A"] += R4[2]
R5 = R(ref="R5", value="1k"); VBUS += R5[1]; D4["A"] += R5[2]
CHRG += U2["CHRG"]; STDBY += U2["STDBY"]

# ----------------------------------------------------------------------------
# battery pack: 2 x 18650 in parallel (fit 1 or 2) + DW01A/FS8205A protection
# ----------------------------------------------------------------------------
BT1 = BATT(ref="BT1", value="18650"); BT2 = BATT(ref="BT2", value="18650 (optional 2nd cell)")
J5 = JST2(ref="J5", value="BAT ALT", remark="alternative: wire-lead holder / pouch cell, parallel to BT1/BT2")
for b in (BT1, BT2):
    BATP += b["+"]; CELLN += b["-"]
BATP += J5[1]; CELLN += J5[2]

U3 = DW01(ref="U3", value="DW01A")
Q1 = FS8205(ref="Q1", value="FS8205A")
R6 = R(ref="R6", value="100R", remark="DW01 VCC filter"); BATP += R6[1]; DW_VCC += R6[2], U3["VCC"]
C3 = C(ref="C3", value="100nF"); DW_VCC += C3[1]; CELLN += C3[2]
CELLN += U3["GND"], U3["TD"], Q1["S1"]
R7 = R(ref="R7", value="1k", remark="DW01 CS sense"); GND += R7[1]; DW_CS += R7[2], U3["CS"]
OD += U3["OD"], Q1["G1"]          # discharge FET (source at CELL-)
OC_ += U3["OC"], Q1["G2"]         # charge FET (source at GND)
GND += Q1["S2"]
FETD += Q1[5], Q1[6], Q1[7], Q1[8]

# ----------------------------------------------------------------------------
# load sharing: VBUS -> D1 -> VSYS ; BAT+ -> Q2 (P-FET, gate = VBUS) -> VSYS
# ----------------------------------------------------------------------------
D1 = D_SMA(ref="D1", value="SS34", remark="USB -> VSYS"); VBUS += D1["A"]; VSYS += D1["K"]
Q2 = PFET8(ref="Q2", value="AO4407A", remark="load-share P-FET; off while USB present")
BATP += Q2[5], Q2[6], Q2[7], Q2[8]
VSYS += Q2[1], Q2[2], Q2[3]
VBUS += Q2["G"]
R8 = R(ref="R8", value="100k", remark="VBUS bleed / Q2 gate pull-down"); VBUS += R8[1]; GND += R8[2]

# ----------------------------------------------------------------------------
# boost VSYS -> +5V (MT3608, 5.1 V) and switched LED rail
# ----------------------------------------------------------------------------
U4 = MT3608(ref="U4", value="MT3608")
VSYS += U4["IN"]; GND += U4["GND"]
L1 = L(ref="L1", value="4.7uH 4A", remark="e.g. Bourns SRN6045TA-4R7Y or any 6x6 shielded, Isat >= 4 A"); VSYS += L1[1]; SWN += L1[2], U4["SW"]
D2 = D_SMA(ref="D2", value="SS34"); SWN += D2["A"]; V5 += D2["K"]
R9 = R(ref="R9", value="75k", remark="FB divider: Vout = 0.6*(1+75/10) = 5.1 V"); V5 += R9[1]; FB += R9[2], U4["FB"]
R10 = R(ref="R10", value="10k"); FB += R10[1]; GND += R10[2]
for ref in ("C4", "C5"):
    c = C0805(ref=ref, value="22uF 10V"); VSYS += c[1]; GND += c[2]
for ref in ("C6", "C7"):
    c = C0805(ref=ref, value="22uF 10V"); V5 += c[1]; GND += c[2]
LED_EN += U4["EN"]

Q3 = PFET(ref="Q3", value="AO3401A", remark="LED rail switch"); V5 += Q3["S"]; VLED += Q3["D"]; nLED_EN += Q3["G"]
R12 = R(ref="R12", value="10k", remark="Q3 gate pull-up"); V5 += R12[1]; nLED_EN += R12[2]
Q4 = NFET(ref="Q4", value="2N7002", remark="inverts LED_EN for Q3"); LED_EN += Q4["G"]; GND += Q4["S"]; nLED_EN += Q4["D"]
R11 = R(ref="R11", value="100k", remark="LED_EN pull-down: LEDs off during boot"); LED_EN += R11[1]; GND += R11[2]
C8 = CP(ref="C8", value="100uF 6.3V", remark="LED rail bulk"); VLED += C8["+"]; GND += C8["-"]

# ----------------------------------------------------------------------------
# 3.3 V LDO + power switch
# ----------------------------------------------------------------------------
U5 = AP2112(ref="U5", value="AP2112K-3.3")
VSYS += U5["VIN"]; GND += U5["GND"]; V3 += U5["VOUT"]; SYS_EN += U5["EN"]
C9 = C(ref="C9", value="1uF"); VSYS += C9[1]; GND += C9[2]
C10 = C0805(ref="C10", value="10uF 10V"); V3 += C10[1]; GND += C10[2]
SW1 = SW_SLIDE(ref="SW1", value="POWER", remark="ON = SYS_EN high; only switches the LDO enable (tiny current)")
SYS_EN += SW1["COM"]; VSYS += SW1[1]; GND += SW1[3]

# ----------------------------------------------------------------------------
# ESP32 + decoupling + buttons + touch + sensing + expansion
# ----------------------------------------------------------------------------
U1 = ESP32(ref="U1", value="ESP32-WROOM-32E-N4")
GND += U1[1], U1[15], U1[38], U1[39]
V3 += U1["3V3"]
C11 = C(ref="C11", value="100nF"); V3 += C11[1]; GND += C11[2]
C12 = C0805(ref="C12", value="10uF 10V"); V3 += C12[1]; GND += C12[2]
EN += U1["EN"]; IO0 += U1["IO0"]
R18 = R(ref="R18", value="10k"); V3 += R18[1]; EN += R18[2]
C13 = C(ref="C13", value="1uF", remark="EN reset delay"); EN += C13[1]; GND += C13[2]
R19 = R(ref="R19", value="10k"); V3 += R19[1]; IO0 += R19[2]
SW2 = SW_TACT(ref="SW2", value="RESET"); EN += SW2[1]; GND += SW2[2]
SW3 = SW_TACT(ref="SW3", value="BOOT"); IO0 += SW3[1]; GND += SW3[2]

LED_DATA += U1["IO2"]
LED_EN += U1["IO16"]
TOUCH += U1["IO4"]
VBAT_S += U1["IO35"]
VBUS_D += U1["IO34"]
TX += U1["TXD0"]; RX += U1["RXD0"]
IO25 += U1["IO25"]; IO26 += U1["IO26"]; IO32 += U1["IO32"]; IO33 += U1["IO33"]
# unused module pins left open (SKiDL NC marker)
for pn in (4, 5, 12, 13, 14, 16, 23, 28, 29, 30, 31, 33, 36, 37):
    U1[pn] += Net.fetch("NC_" + str(pn))  # explicit no-connect stubs (dropped by ERC as single-pin nets)

R22 = R(ref="R22", value="1k", remark="touch series / ESD; 0R also fine"); TOUCH += R22[1]; TOUCH_PAD += R22[2]
J3 = JST2(ref="J3", value="TOUCH", remark="1 = pad, 2 = GND (optional shield)"); TOUCH_PAD += J3[1]; GND += J3[2]

R14 = R(ref="R14", value="100k", remark="VBAT divider top (x2.0 in WLED battery usermod)"); BATP += R14[1]; VBAT_S += R14[2]
R15 = R(ref="R15", value="100k"); VBAT_S += R15[1]; GND += R15[2]
C16 = C(ref="C16", value="100nF"); VBAT_S += C16[1]; GND += C16[2]
R16 = R(ref="R16", value="100k", remark="VBUS present detect"); VBUS += R16[1]; VBUS_D += R16[2]
R17 = R(ref="R17", value="100k"); VBUS_D += R17[1]; GND += R17[2]
C17 = C(ref="C17", value="100nF"); VBUS_D += C17[1]; GND += C17[2]

J4 = HDR6(ref="J4", value="EXP", remark="3V3 GND IO25 IO26 IO32 IO33 (IR receiver, extra buttons, sensors)")
V3 += J4[1]; GND += J4[2]; IO25 += J4[3]; IO26 += J4[4]; IO32 += J4[5]; IO33 += J4[6]

# ----------------------------------------------------------------------------
# LED data level shift + LED connector
# ----------------------------------------------------------------------------
U7 = AHCT125(ref="U7", value="74AHCT1G125")
V5 += U7["VCC"]; GND += U7["GND"]; LED_DATA += U7["A"]; LED_DATA5 += U7["Y"]; nLED_EN += U7["OE#"]
C15 = C(ref="C15", value="100nF"); V5 += C15[1]; GND += C15[2]
R13 = R(ref="R13", value="330R", remark="LED data series termination"); LED_DATA5 += R13[1]; LED_OUT += R13[2]
J2 = JST3(ref="J2", value="LED RING", remark="1 = VLED (+5V), 2 = GND, 3 = DATA -> LED ring(s) in the head, via the stem"); VLED += J2[1]; GND += J2[2]; LED_OUT += J2[3]

# ----------------------------------------------------------------------------
# USB-UART (CH340C at 3.3 V) + auto-reset
# ----------------------------------------------------------------------------
U6 = CH340(ref="U6", value="CH340C")
V3 += U6["VCC"], U6["V3"]        # V3 tied to VCC => 3.3 V operation
GND += U6["GND"], U6["R232"]
DP += U6["UD+"]; DM += U6["UD-"]
RX += U6["TXD"]                  # CH340 TXD -> ESP RXD0
TX += U6["RXD"]                  # ESP TXD0 -> CH340 RXD
DTR += U6["DTR#"]; RTS += U6["RTS#"]
C14 = C(ref="C14", value="100nF"); V3 += C14[1]; GND += C14[2]
R20 = R(ref="R20", value="12k"); DTR += R20[1]; DTR_B += R20[2]
R21 = R(ref="R21", value="12k"); RTS += R21[1]; RTS_B += R21[2]
Q5 = NPN(ref="Q5", value="MMBT3904", remark="auto-reset: EN"); DTR_B += Q5["B"]; RTS += Q5["E"]; EN += Q5["C"]
Q6 = NPN(ref="Q6", value="MMBT3904", remark="auto-reset: IO0"); RTS_B += Q6["B"]; DTR += Q6["E"]; IO0 += Q6["C"]

# mounting holes (match the enclosure bosses)
for i in range(1, 5):
    MH(ref=f"H{i}", value="M3")


# ----------------------------------------------------------------------------
# outputs
# ----------------------------------------------------------------------------
default_circuit = U1.circuit   # the implicit circuit every part above was added to


def write_bom(path):
    groups = defaultdict(list)
    for p in default_circuit.parts:
        key = (p.value, getattr(p, "footprint", ""), getattr(p, "mpn", ""), getattr(p, "description", ""))
        groups[key].append(p)
    rows = []
    for (val, fp, mpn, desc), parts in groups.items():
        refs = sorted((p.ref for p in parts), key=lambda r: (r.rstrip("0123456789"), int("".join(ch for ch in r if ch.isdigit()) or 0)))
        notes = "; ".join(sorted({getattr(p, "remark", "") for p in parts if getattr(p, "remark", "")}))
        rows.append([", ".join(refs), len(parts), val, desc, mpn, fp.split(":")[-1], notes])
    rows.sort(key=lambda r: (r[0].split(",")[0].rstrip("0123456789"), int("".join(ch for ch in r[0].split(",")[0] if ch.isdigit()) or 0)))
    with open(path, "w", newline="") as f:
        w = csv.writer(f)
        w.writerow(["Refs", "Qty", "Value", "Description", "MPN / example part", "Footprint", "Notes"])
        w.writerows(rows)
    return rows
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

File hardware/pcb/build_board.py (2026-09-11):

#!/usr/bin/env python3
"""
TableLight controller PCB - board generator (KiCad 7 pcbnew Python API).

Builds hardware/pcb/kicad/tablelight.kicad_pcb from:
  * the circuit in tablelight_netlist.py (SKiDL)          -> footprints + nets
  * the enclosure parameters in cad/tablelight.py         -> outline, holes, connector positions
  * the PLACEMENT table below                             -> component positions
then autoroutes with freerouting (Specctra DSN/SES round trip), pours GND on both
layers, runs DRC and exports the PCBWay fabrication package (Gerbers, drill, BOM, CPL).

    python3 hardware/pcb/build_board.py --stage place      # board with footprints + nets, no tracks
    python3 hardware/pcb/build_board.py --stage route      # + freerouting (needs java + freerouting.jar)
    python3 hardware/pcb/build_board.py --stage finish     # + zones, DRC, fab exports  (default: all)

Coordinates: KiCad convention, mm, origin = board centre, +Y DOWN, components on F.Cu.
In the lamp the component side faces DOWN, so this view is the mirror image of the base seen from above.
The USB-C is at +Y here (lamp -Y), the ESP32 antenna at -Y (lamp +Y).
"""
import argparse
import csv
import glob
import math
import os
import re
import shutil
import subprocess
import sys
import zipfile

import pcbnew
from pcbnew import VECTOR2I, FromMM

HERE = os.path.dirname(os.path.abspath(__file__))
ROOT = os.path.abspath(os.path.join(HERE, "..", ".."))
sys.path.insert(0, os.path.join(ROOT, "cad"))
sys.path.insert(0, HERE)
import tablelight as cad  # noqa: E402

P, D = cad.P, cad.D
KICAD_DIR = os.path.join(HERE, "kicad")
FAB_DIR = os.path.join(HERE, "fab")
PCB_PATH = os.path.join(KICAD_DIR, "tablelight.kicad_pcb")
FP_LIB_DIR = "/usr/share/kicad/footprints"
FREEROUTING_JAR = os.environ.get("FREEROUTING_JAR", os.path.join(HERE, "tools", "freerouting.jar"))

BOARD_R = P["pcb_r"]
SLOT_W, SLOT_H = P["pcb_slot"]

# net classes -----------------------------------------------------------------
POWER_NETS = {"BAT+", "CELL-", "PROT_FET_D", "VSYS", "+5V", "VLED", "BOOST_SW"}
VBUS_NETS = {"VBUS"}            # 0.4 mm: the USB-C VBUS pads are 0.6 mm wide with 0.2 mm to the GND pads
TRACK_DEFAULT, TRACK_POWER, TRACK_VBUS = 0.25, 0.8, 0.4
CLEARANCE = 0.2
VIA_D, VIA_DRILL = 0.7, 0.35


def mm(x, y):
    return VECTOR2I(FromMM(x), FromMM(y))


def polar(r, deg):
    return (r * math.cos(math.radians(deg)), r * math.sin(math.radians(deg)))


def lamp_angle_to_kicad(a):
    """lamp top-view angle -> KiCad angle (view from component side, Y down):
    mirror X (view) then flip Y (KiCad) == rotate by 180 - a then negate y == angle -(180 - a) ... simplified:"""
    x, y = math.cos(math.radians(a)), math.sin(math.radians(a))
    xv, yv = -x, y          # mirror X: lamp top view -> component-side view
    xk, yk = xv, -yv        # KiCad Y down
    return math.degrees(math.atan2(yk, xk))


# -----------------------------------------------------------------------------
# PLACEMENT  ref -> (x, y, rotation_deg)   [KiCad mm, F.Cu]
# -----------------------------------------------------------------------------
USB_ANG = lamp_angle_to_kicad(P["usb_angle"])          # 90 deg -> +Y
SW_ANG = lamp_angle_to_kicad(P["sw_angle"])
LED_ANGS = [lamp_angle_to_kicad(a) for a in P["led_angles"]]
HOLDER_Y = SLOT_H / 2 + 1.0 + 20.8 / 2                 # 14.4 -> holder courtyards y 3.5 .. 25.3

ESP_Y = -38.0            # footprint origin; module body spans y -53.8 .. -28.2, antenna end at the board edge
USB_Y = 56.0 - 3.7       # mating face 1 mm past the board edge (r = 55)
SW_R = 49.25             # slide switch: pins at this radius, body toward the edge, actuator through the wall slot

PLACEMENT = {
    # --- mounting holes (deck bosses) -------------------------------------------------
    **{f"H{i+1}": (*polar(P["pcb_hole_r"], 45 + 90 * i), 0) for i in range(4)},
    # --- battery holders: long axis along X; pad 1 ('+') toward -X -----------------------
    "BT1": (0, -HOLDER_Y, 0),
    "BT2": (0, HOLDER_Y, 0),
    # --- ESP32 + support (top region, y < -25) -----------------------------------------
    "U1": (0, ESP_Y, 0),
    "C11": (-12.5, -46.0, 90), "C12": (-12.5, -42.5, 90),      # 3V3 decoupling next to pin 2
    "R18": (-12.5, -39.0, 90), "C13": (-12.5, -35.5, 90),      # EN pull-up + RC
    "R19": (12.5, -29.5, 90),                                  # IO0 pull-up (pin 25)
    "R22": (12.5, -33.5, 90),                                  # touch series (pin 26, IO4)
    "R14": (-16.0, -40.0, 90), "R15": (-19.0, -40.0, 90), "C16": (-22.0, -40.0, 90),   # VBAT divider -> IO35 (pin 7)
    "R16": (-16.0, -36.5, 90), "R17": (-19.0, -36.5, 90), "C17": (-22.0, -36.5, 90),   # VBUS detect -> IO34 (pin 6)
    "U5": (20.0, -33.0, 0), "C9": (16.5, -36.5, 0), "C10": (23.5, -36.5, 0),           # 3.3 V LDO
    "U7": (30.0, -30.0, 0), "C15": (30.0, -33.5, 0), "R13": (34.5, -30.0, 90),         # level shifter
    "J4": (-20.5, -30.0, 270),                                                        # expansion header (origin = pin 1; pins run toward -X)
    "SW2": (-27.0, -37.0, 0), "SW3": (-40.0, -28.5, 0),                                 # RESET / BOOT
    # --- side connectors, wires run between the holders into the centre slot --------------
    "J2": (48.5, 4.0, 90), "J3": (-48.5, -4.0, 90), "J5": (-47.0, 17.0, 90),
    "C8": (47.5, -12.0, 90),
    # --- USB-C, ESD, UART, auto-reset, buttons (bottom-left) ---------------------------------
    "J1": (0, USB_Y, 0),
    "R1": (5.5, 43.0, 0), "R2": (5.5, 45.0, 0), "C1": (9.5, 47.0, 0),
    "U8": (-6.0, 44.5, 0),
    "U6": (-13.5, 42.0, 0), "C14": (-8.5, 37.5, 90),
    "Q5": (-21.5, 43.5, 0), "Q6": (-21.5, 39.5, 0), "R20": (-27.5, 40.0, 90), "R21": (-27.5, 37.0, 90),
    "D3": (*polar(51.0, LED_ANGS[0]), LED_ANGS[0] + 90), "D4": (*polar(51.0, LED_ANGS[1]), LED_ANGS[1] + 90),
    "R4": (-29.0, 42.5, 90), "R5": (-31.5, 40.5, 90),
    # --- protection at the '-' end ... (left, near the BT pad 2 side is +X; CELL- pads are pad 2 at +X!) ---
    "Q1": (-41.5, 28.5, 0), "U3": (-34.0, 28.0, 0),
    "R6": (-30.0, 28.0, 90), "C3": (-27.5, 28.0, 90), "R7": (-25.0, 28.0, 90),
    # --- charger + load share ----------------------------------------------------------------
    "U2": (13.0, 42.0, 0), "R3": (8.0, 37.5, 90), "C2": (15.0, 47.5, 0),
    "D1": (12.5, 35.0, 0), "Q2": (12.5, 30.0, 0), "R8": (20.0, 29.0, 90),
    # --- boost + LED rail switch (right) -----------------------------------------------------
    "U4": (45.7, 24.0, 90), "L1": (47.3, 16.0, 90), "D2": (40.0, 28.0, 0),    # U4 turned: pad rows face +/-Y, stubs stay off the edge
    "R9": (32.5, 28.5, 90), "R10": (34.5, 28.5, 90),
    "C4": (42.0, 31.5, 90), "C5": (17.5, 29.5, 90), "C6": (28.0, 33.0, 0), "C7": (28.0, 35.0, 0),   # C4 at the boost, C5 at the VSYS source
    "Q3": (23.5, 33.0, 0), "Q4": (19.0, 33.0, 0), "R11": (19.0, 36.5, 0), "R12": (23.5, 36.5, 0),
    "SW1": None,   # computed: pins centred at polar(SW_R, SW_ANG), actuator outward
}
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

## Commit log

2026-09-11 Add TableLight: 3D-printable WLED table lamp (CAD, STLs, PCB design, docs)
    Classic disc-base / stem / cone-shade rechargeable table lamp:
    - cad/tablelight.py: parametric CAD (trimesh + manifold), exports six
    print-ready STLs and preview renders; all dimensions in one block
    - hardware/pcb: SKiDL circuit -> KiCad netlist, BOM CSV, net-by-net
    schematic tables; board outline DXF and placement drawing derived
    from the enclosure parameters; design notes and bring-up procedure
    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
    [base_bottom_plate.stl, base_shell.stl, bom_pcb.csv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]
2026-09-11 Add KiCad board generator, fab ordering notes, move switch/LED openings
    - hardware/pcb/build_board.py: builds the Ø110 board with pcbnew (placement
    table, nets from the SKiDL circuit, outline, keep-outs, freerouting DSN/SES
    round trip, GND pours, DRC, Gerber/drill/BOM/CPL export for PCBWay)
    - footprints switched to names present in the KiCad 7 library
    - enclosure: power switch moved to -120 deg, charge LEDs to -66/-61 deg so
    the switch body clears the USB-UART area; STL and renders regenerated
    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
    [base_shell.stl, bom_pcb.csv, outline.dxf]
2026-09-11 Board generator: SES import, edge keep-out ring, VBUS track class, placement tweaks
    Claude-Session: https://claude.ai/code/session_019pemffm2ynpntBzdkVem8C
    [base_shell.stl, outline.dxf]
2026-09-11 Board generator: escape stubs for fine-pitch power/USB pads, fixed wiring in DSN
    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
    [build_board.py]
2026-09-11 Add routed KiCad board and PCBWay fabrication package
    - hardware/pcb/kicad/tablelight.kicad_pcb: Ø110 two-layer board, all 72
    footprints placed, autorouted with freerouting, GND pours on both layers,
    DRC clean (0 unconnected, 0 clearance/edge/hole/courtyard errors)
    - hardware/pcb/fab/: Gerber + Excellon zip, PCBWay assembly BOM and
    pick-and-place CSV, ordering notes and pre-order checklist
    - build_board.py: escape stubs for fine-pitch pads, fixed wiring in the
    DSN, dangling-track pruning, real-vs-cosmetic DRC exit status
    - docs: board renders (top/bottom), PCB README updated
    Claude-Session: https://claude.ai/code/session_019p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
    [tablelight-bom.csv, tablelight.kicad_pcb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]
